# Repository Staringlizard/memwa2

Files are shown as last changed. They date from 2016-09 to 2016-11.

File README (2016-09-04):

*** Building software:

1. Download the gnu arm cross compiler package
2. Download memwa2 source code from github
3. Extract everything and enter folder memwa2
4. Modify PATH variable to include the bin folder for cross compiler
5. Make
6. Done

*** Flashing software:

1. Copy the file ./out_target/target.bin to the root directory on the sdcard
2. Insert the SD card and startup hardware
3. New firmware will automatically start flash procedure if firmware file is found
4. If software is flashed successfully the target.bin file will be removed

*** SD card:

There are some folders that can be added to the sdcard
in order to configure the software and to run programs.

"conf" folder

  "key.cfg" file

    This file contain entries like this -> "2A:0,0". This specific entry
    means that the USB scan code 2A (back space) should be mapped
    to the commodore key matrix equivalent of 0 and 0. In other words
    the CIA1 IC portA bit 0 and CIA1 portB bit 0 will have a connection.

  "palette.cfg" file

    This file contains all c64 colors in RGB888 format. In addition to this
    it also contains 3 extra colors that are used for text background,
    text forground and marker.

"d64, t64, tap, prg" folders

    Here all programs should be stored.

"rom" folder

    "cc_brom.bin"

      Contains the basic rom.

    "cc_crom.bin"

      Contains the char rom.

    "cc_krom.bin"

      Contains the kernal rom.

    "dd_dos.bin"

      Contains the disk drive rom.

"res" folder

  Contains the bitmaps used in menu.

*** Startup:

1. Unzip the sdcard.zip file onto an sdcard
2. Insert sdcard into memwa2 board
3. Power on

*** Key shortcuts:

Ctrl + Esc: Menu
Ctrl + F1: Show info
Ctrl + F2: Activate/deactivate disk drive
Ctrl + F3: Activate/deactivate freq lock
Ctrl + F4: Full/half emulated frame rate
Ctrl + F5: Play/Stop datasette
Ctrl + F6: Clear last message
Ctrl + F9: C64 palette
Ctrl + F10: C64 soft reset
Ctrl + F11: C64 hard reset
Ctrl + F12: Hardware reset
Joystick A: Arrow keys
Joystick B: Num keys

*** Design:

             +-----+ +-----+ +-----+ +-----+ +-----+ +-----+    +-----+ +-----+ +-----+ +-----+     ^
Emulators    | vic | | tap | | sid | | cia | | cpu | | bus |    | via | | fdd | | cpu | | bus |     |
             +-----+ +-----+ +-----+ +-----+ +-----+ +-----+    +-----+ +-----+ +-----+ +-----+     |
                                                                                                    |
             +---------------------------------------------+    +-----------------------------+     +
             |                   emuccif                   |    |            emuddif          |  Emulator
             +----------------------+----------------------+    +---------------+-------------+
Interface                           |                                           |
             +----------------------+-------------------------------------------+-------------+
             |                                    hostif                                      |  Hardware
             +--------------------------------------------------------------------------------+     +
                                                                                                    |
                                               +-----------+                                        |
Higher layer                           +-------+    sm     |                                        |
                                       |       +-----+-----+                                        |
                                       |             |                                              |
                                 +-----+----+  +-----+-----+  +-----------+                         |
Util layer                       |   stage  |  |   keybd   |  |  console  |                         |
                                 +----------+  +-----+-----+  +---------+-+                         |
                                                     |                  |                           |
                                 +-----------+       | +------------+   |                           |
Mware layer                      |   fatfs   |       +-+    usb     +---+                           |
                                 +-----------+         +------------+                               |
                                                                                                    |
             +-------+ +---+ +----+ +-----+ +---+ +------+ +-----+ +------+ +-------+ +-------+     |
Driver layer |adv7511| |crc| |disp| |joyst| |rng| |sdcard| |sdram| |sidbus| |usbd_ll| |usbh_ll|     |
             +-------+ +---+ +----+ +-----+ +---+ +------+ +-----+ +------+ +-------+ +-------+     |
                                                                                                    |
             +--------------------------------------------------------------------------------+     |
HAL layer    |                                      HAL                                       |     |
             +--------------------------------------------------------------------------------+     v

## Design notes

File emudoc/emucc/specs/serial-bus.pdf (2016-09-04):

IEC-bus documentation as used for the 1541-III

J. Derogee | Page 1 | 2008-02-24

# IEC disected

This document describes the IEC-bus information gathered during the development of the 1541-III.

J. Derogee | Page 2 | 2008-02-24

General info:

The serial (IEC) bus uses a synchronous protocol. There are three lines: DATA, CLK, and -ATN. The lines are driven by a 6526 CIA on the C-64, through open-collector inverters (7406's); 1 kohm pull-up resistors are used. The 1541 and 1571 drives do the same, but they don't drive the -ATN line, and they use 6522 VIA's. The lines are also read, directly by the C-64. Address $DD00 (PA of CIA2) is used by the C-64. Bit 3 is ATN OUT, bit 4 is -CLK OUT, bit 5 is -DATA OUT, bit 6 is CLK IN, and bit 7 is DATA IN.

A device's identity is usually stored in RAM after boot up, so a drive POKE will let it change to anything in the range 0-30. The C64 kernal (unless patched) prevents 0-3 from actually going down the serial bus....

CBM Device ID’s
Device ID | Device type
0 | Keyboard
1 | Cassette port
2 | RS232 on user port or second cassette on older units
3 | Screen
4 | Printer
5 | Printer
6 | Typically plotter device
7 | Second plotter? Also used by a freeze cartridges named TurboTape, but that's only an internal definition
8 | Primary Disk Drive
9 | Disk Drive
10 | Disk Drive Also used by some serial-to-parallel printer interface cartridges
11 | Disk Drive
12 | Disk Drive
13 | Disk Drive
14 | Disk Drive Sometimes used by some serial-to-parallel printer interface cartridges
15 | Disk Drive
16-30 | Unknown
31 | Device #31 is reserved as a command to all devices Devices will not ignore a command to #31, since they cannot do this. Sending a TALK command to #31 means UNTALK, sending a LISTEN to #31 means UNLISTEN. This however is just a statement found on the web and has not been verified by other sources.

J. Derogee | Page 3 | 2008-02-24

Regarding the signals on the bus: 0V = TRUE or PULLED DOWN
5V = FALSE or RELEASED

Regarding the data on the bus: 0V = logical 0
5V = logical 1

Bytes are sent with low bit first. Data is valid on rising edge of clock

CBM Serial Bus Control Codes
Base address | Command name and details
20 | LISTEN + device number (0-30)
3F | UNLISTEN
40 | TALK + device number (0-30)
5F | UNTALK
60 | OPEN CHANNEL / DATA + Secondary Address / channel (0-15)
70 | -Undefined-
80 | -Undefined-
90 | -Undefined-
A0 | -Undefined-
B0 | -Undefined-
C0 | -Undefined-
D0 | -Undefined-
E0 | CLOSE + Secondary Address / channel (0-15)
F0 | OPEN + Secondary Address / channel (0-15)
/ | = | byte is send under attention (ATN low)
↑ | = | bus turn around (computer is set to slave)
↓ | = | bus turn around (computer is set to master (normal situation)

Note: the device (1541) is called by the computer (C64)

J. Derogee | Page 4 | 2008-02-24

This article appeared in Compute! July 1983 and is Copyrighted 1983 by Jim Butterfield.

HOW THE VIC/64 SERIAL BUS WORKS By Jim Butterfield

The Serial bus connects VIC or Commodore 64 to its major peripherals, especially disk and tape. The workings of this interface have been a source of bafflement to most of us. We know that it's somehow related to the IEEE-488 bus which is used on PET and CBM computers. But it has fewer wires, and it's slower. For anyone interested in interfacing details, this article will clear up the mystery.

GROUND RULES
To understand the workings of this bus, you must work through a few concepts. Later, we'll get technical for this who want it. The bus, like the IEEE, has two modes of operation: Select mode, in which the computer calls all devices and asks for a specific device to remain connected after the call ("Jones, would you stay in my office after the meeting?"); and Data mode, in which actual information is transmitted ("Jones, I've decided to give you a raise"). Select mode is invoked by the use of a special control line called "Attention," or ATN. By using Select mode, you can call in any device you choose, but you may need to do more before you transmit data. You might have several disk files in progress - writing some and reading others – and when you select the disk, device 8, you'll still need to specify which "part" of the disk you want to reach: subchannel 3, subchannel 15, or whatever. To do this, we use a "secondary address" which usually signals a subsystem within a specific device. That goes in as part of the command during Select mode. Finally, we may need to send other control information: the name of the file we wish to open, for example. That's not data; it's device setup information, so we also send it in Select mode. But the main part is: you select a device, and then you send to it or receive from it. Finally, you shut it off. All devices are connected, but only the one you have selected will listen or talk.

If you're not into volts and signals and things, the rest of this article may not do much for you. I want to talk about technical aspects of the bus. First, all the data flows over two wires; They are called the Clock line and the Data line. There are other wires used for control purposes, but the data uses only the two main ones. All wires connect to all devices. The wires don't go "one way"; any device can put a ground on a signal line, and all other devices will see it. Indeed, that's the secret of how it works: each wire serves as a common signal bus.

When no device puts a ground on a signal line, the voltage rises to almost five volts. We call this the "false" logic condition of the wire. If any device rounds the line, the voltage drops to zero; we call this the "true" condition of the line. Note that if two devices signal "true" on a line (by grounding it), the effect is exactly the same as if only one has done so: the voltage is zero and that's that. We can summarize this as an important set of logic rules:

-A line will become "true" (PULLED DOWN, or 0V) if one or more devices signal true;
-A line will become "false" (RELEASED, or 5V) only if all devices signal false.

Remember that we have several lines, but the important ones for information transmission are the Clock line and the Data line. Let's watch them work.

J. Derogee | Page 5 | 2008-02-24

TRANSMISSION: STEP ZERO
Let's look at the sequence when a character is about to be transmitted. At this time, both the Clock line and the Data line are being held down to the true tate. With a test instrument, you can't tell who's doing it, but I'll tell you: the talker is holding the Clock line true, and the listener is holding the Data line true. There could be more than one listener, in which case all of the listeners are holding the Data line true. Each of the signals might be viewed as saying, "I'm here!".
STEP 1: READY TO SEND
Sooner or later, the talker will want to talk, and send a character. When it's ready to go, it releases the Clock line to false. This signal change might be translated as "I'm ready to send a character." The listener must detect this and respond, but it doesn't have to do so immediately. The listener will respond to the talker's "ready to send" signal whenever it likes; it can wait a long time. If it's a printer chugging out a line of print, or a disk drive with a formatting job in progress, it might hold back for quite a while; there's no time limit.
STEP 2: READY FOR DATA
When the listener is ready to listen, it releases the Data line to false. Suppose there is more than one listener. The Data line will go false only when all listeners have released it - in other words, when all listeners are ready to accept data. What happens next is variable. Either the talker will pull the Clock line back to true in less than 200 microseconds - usually within 60 microseconds - or it will do nothing. The listener should be watching, and if 200 microseconds pass without the Clock line going to true, it has a special task to perform: note EOI.

INTERMISSION: EOI
If the Ready for Data signal isn't acknowledged by the talker within 200 microseconds, the listener knows that the talker is trying to signal EOI. EOI, which formally stands for "End of Indicator," means "this character will be the last one." If it's a sequential disk file, don't ask for more: there will be no more. If it's a relative record, that's the end of the record. The character itself will still be coming, but the listener should note: here comes the last character. So if the listener sees the 200 microsecond time-out, it must signal "OK, I noticed the EOI" back to the talker, I does this by pulling the Data line true for at least 60 microseconds, and then releasing it. The talker will then revert to transmitting the character in the usual way; within 60 microseconds it will pull the Clock line true, and transmission will continue. At this point, the Clock line is true whether or not we have gone through the EOI sequence; we're back to a common transmission sequence.
STEP 3: SENDING THE BITS
The talker has eight bits to send. They will go out without handshake; in other words, the listener had better be there to catch them, since the talker won't wait to hear from the listener. At this point, the talker controls both lines, Clock and Data. At the beginning of the sequence, it is holding the Clock true, while the Data line is released to false. the Data line will change soon, since we'll send the data over it. The eights bits will go out from the character one at a time, with

the least significant bit going first. For example, if the character is the ASCII question mark, which is written in binary as 00011111, the ones will go out first, followed by the zeros. Now, for each bit, we set the Data line true or false according to whether the bit is one or zero. As soon as that's set, the Clock line is released to false, signalling "data ready." The talker will typically have a bit in place and be signalling ready in 70 microseconds or less. Once the talker has signalled "data ready," it will hold the two lines steady for at least 20 microseconds timing needs to be increased to

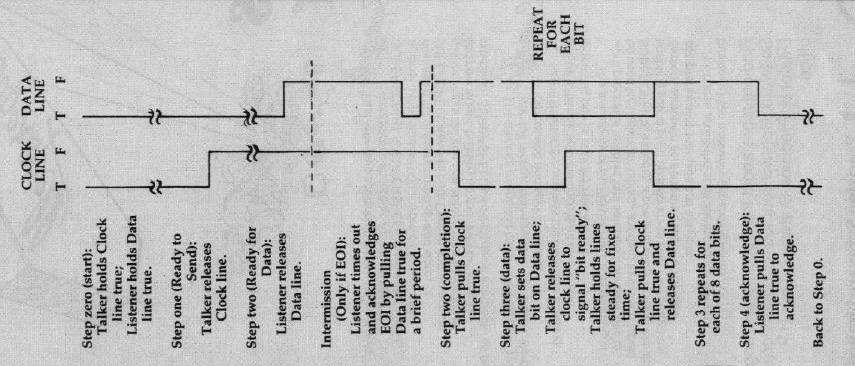
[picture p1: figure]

J. Derogee | Page 6 | 2008-02-24

60 microseconds if the Commodore 64 is listening, since the 64's video chip may interrupt the processor for 42 microseconds at a time, and without the extra wait the 64 might completely miss a bit. The listener plays a passive role here; it sends nothing, and just watches. As soon as it sees the Clock line false, it grabs the bit from the Data line and puts it away. It then waits for the clock line to go true, in order to prepare for the next bit. When the talker figures the data has been held for a sufficient length of time, it pulls the Clock line true and releases the Data line to false. Then it starts to prepare the next bit.

STEP 4: FRAME HANDSHAKE
After the eighth bit has been sent, it's the listener's turn to acknowledge. At this moment, the Clock line is true and the Data line is false. The listener must acknowledge receiving the byte OK by pulling the Data line to true. The talker is now watching the Data line. If the listener doesn't pull the Data line true within one millisecond - one thousand microseconds - it will know that something's wrong and may alarm appropriately.
STEP 5: START OVER
We're finished, and back where we started. The talker is holding the Clock line true, and the listener is holding the Data line true. We're ready for step 1; we may send another character - unless EOI has happened. If EOI was sent or received in this last transmission, both talker and listener "let go." After a suitable pause, the Clock and Data lines are released to false and transmission stops.

ATTENTION!
This is all very well for a transmission that's under way, but how do we set up talker and listener? We use an extra line that overrides everything else, called the ATN, or Attention line. Normally, the computer is the only device that will pull ATN true. When it does so, all other devices drop what they are doing and become listeners. Signals sent by the computer during an ATN period look like ordinary characters - eight bits with the usual handshake - but they are not data. They are "Talk," "Listen," "Untalk," and "Unlisten" commands telling a specific device that it will become (or cease to be) a talker or listener. The commands go to all devices, and all devices acknowledge them, but only the ones with the suitable device numbers will switch into talk and listen mode. These commands are sometimes followed by a secondary address, and after ATN is released, perhaps by a file name. An example might help give an idea of the nature of the communications

J. Derogee | Page 7 | 2008-02-24

that take place. To open for writing a sequential disk file called "XX," the following sequence would be sent with ATN on:DEVICE-8-LISTEN;SECONDARY-ADDRESS-2-OPEN. When ATN switches off, the computer will be waiting as a talker, holding the Clock line true; and the disk will be the listener, holding the Data line true. That's good, because the computer has more to send, and it will transmit: X;X;comma;s;comma;W - the W will be accompanied with an EOI signal. Shortly thereafter, the computer will switch ATN back on and send DEVICE-8-UNLISTEN. The file is now open; later, the computer will want to send data there. It will transmit, with ATN on, DEVICE-8-LISTEN;SECONDARY- ADDRESS-2-DATA. Then the computer releases the ATN line and sends
its data; only the disk will receive the data, and the disk will know to put it onto the file called XX. The last character sent by the computer will also signal EOI. After the computer has sent enough data for the moment, it will pull ATN on again and send DEVICE-8-UNLISTEN. Many bursts of data may goto the file; eventually, the computer will close the file by sending (with ATN on, of course) DEVICE-8-LISTEN;SECONDARY-ADDRESS-2-CLOSE. ATN overrides everything in progress, A disk file might have lots of characters to give to the computer, but the computer wants only a
little data. It accepts the characters it wants, then switches on ATN and commands the disk to Untalk. The disk has not sent EOI, but it will disconnect as commanded. Later, when it's asked to Talk again, it will send more characters.

ATN SEQUENCES
When ATN is pulled true, everybody stops what they are doing. The processor will quickly pull the Clock line true (it's going to send soon), so it may be hard to notice that all other devices release the Clock line. At the same time, the processor releases the Data line to false, but all other devices are getting ready to listen and will each pull Data to true. They had better do this within one millisecond (1000 microseconds), since the processor is watching and may sound an alarm ("device not available") if it doesn't see this take place. Under normal circumstances, transmission now takes place as previously described. The computer is sending commands rather than data, but the characters are exchanged with exactly the same timing and handshakes as before. All devices receive the commands, but only the specified device acts upon it. This results in a curious situation: you can send a command to a nonexistent device (try "OPEN 6,6") - and the computer will not know that there is a problem, since it receives valid handshakes from the other devices. The computer will notice a problem when you try to send or receive data from the nonexistent device, since the unselected devices will have dropped off when ATN ceased, leaving you with nobody to talk to.

TURNAROUND
An unusual sequence takes place following ATN if the computer wishes the remote device to become a talker. This will usually take place only after a Talk command has been sent. Immediately after ATN is released, the selected device will be behaving like a listener. After all, it's been listening during the ATN cycle, and the computer
has been a talker. At this instant, we have "wrong way" logic; the device is holding down the Data line, and the computer is holding the Clock line. We must turn this around. Here's the sequence: the computer quickly realizes what's going on, and pulls the Data line to true (it's already there), as well as releasing the Clock line to false. The device waits for this: when it sees the Clock line go true, it releases the Data line (which stays true anyway since the computer is now holding it down) and then pulls down the Clock line. We're now in our starting position, with the talker (that's the device) holding the Clock true, and the listener (the computer) holding the Data line true. The

J. Derogee | Page 8 | 2008-02-24

computer watches for this state; only when it has gone through the cycle correctly will it be ready to receive data. And data will be signalled, of course, with the usual sequence: the talker releases the Clock line to signal that it's ready to send. The logic sequences make sense. They are hard to watch with a voltmeter or oscilloscope since you can't tell which device is pulling the line down to true. The principles involved are very similar to those on the PET/CBM IEEE-488 bus - the same Talk and Listen commands go out, with secondary addresses and similar features. There are fewer "handshake" lines than on IEEE, and the speed is slower; but the principle is the same.

-End of document-Copyright 1983 by Jim Butterfield (published in Compute!)

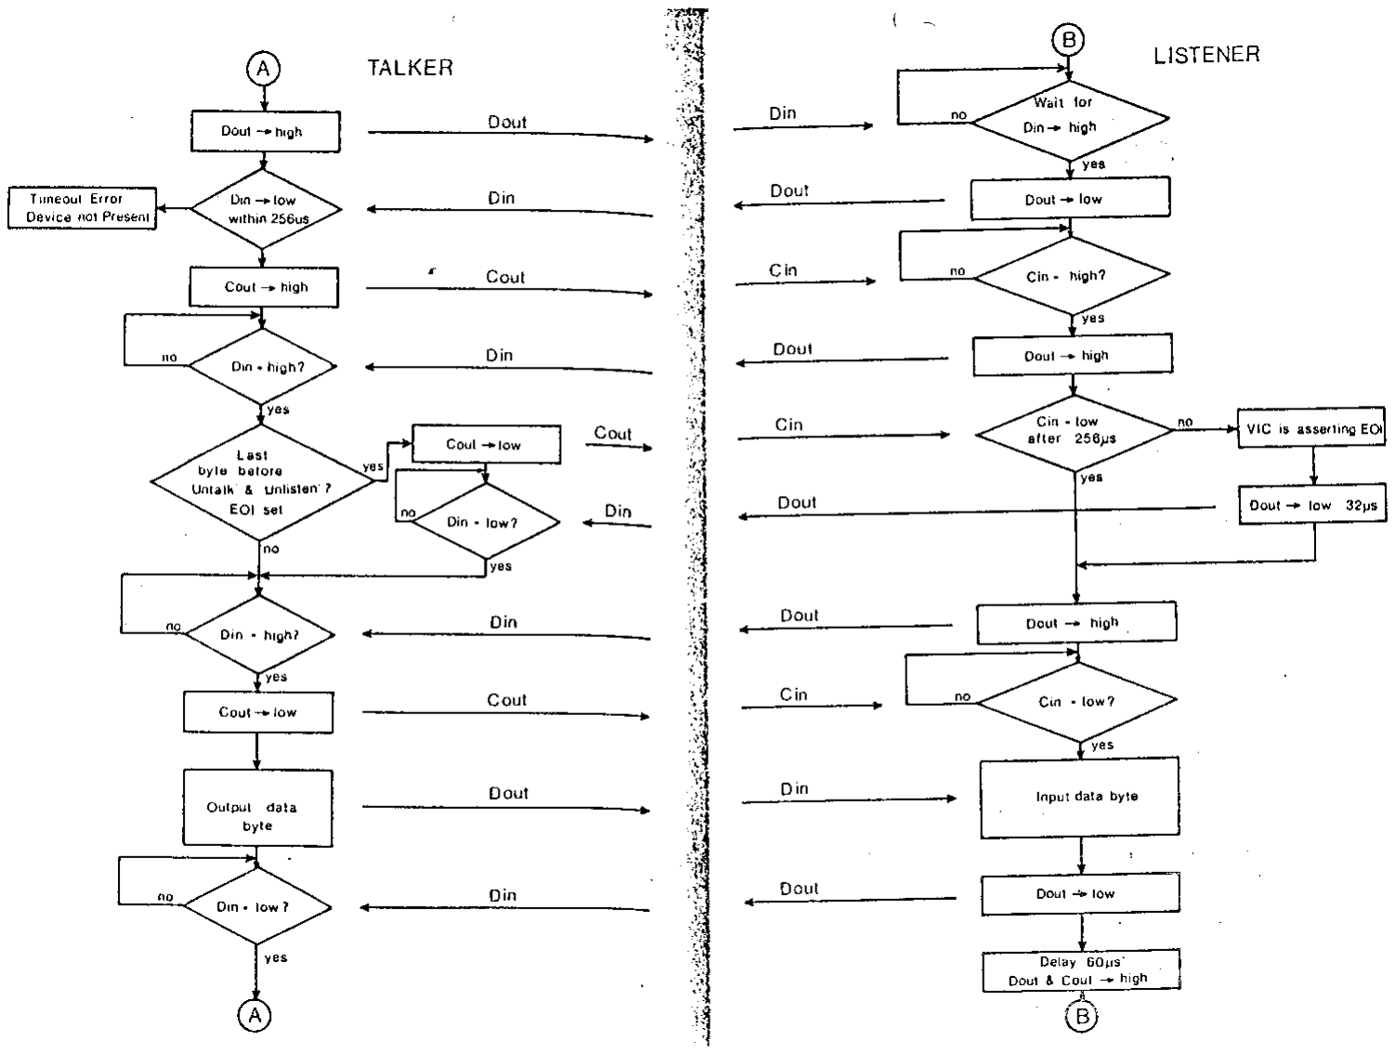
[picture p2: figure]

J. Derogee | Page 9 | 2008-02-24

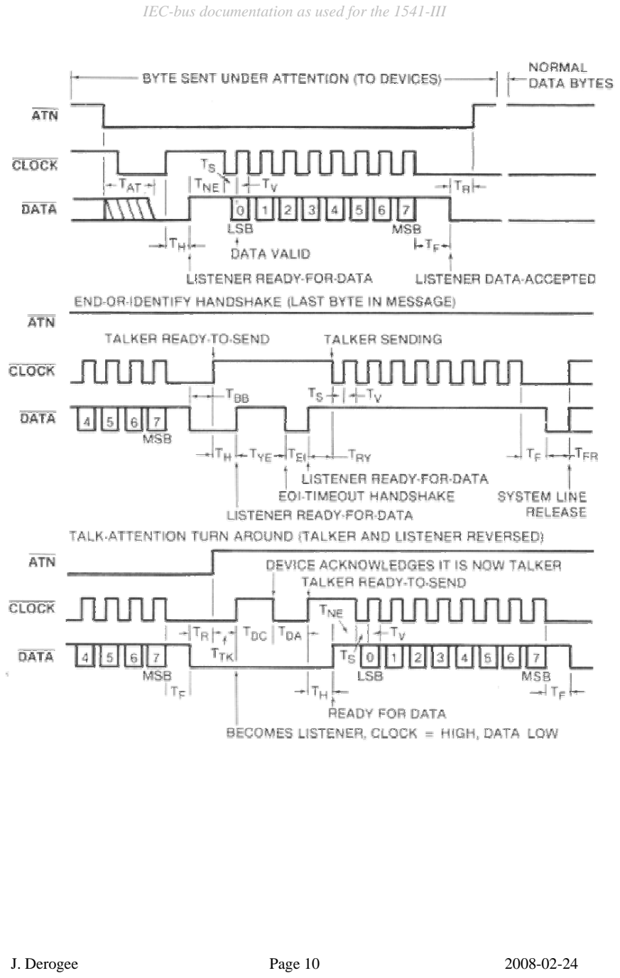
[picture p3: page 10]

J. Derogee | Page 10 | 2008-02-24

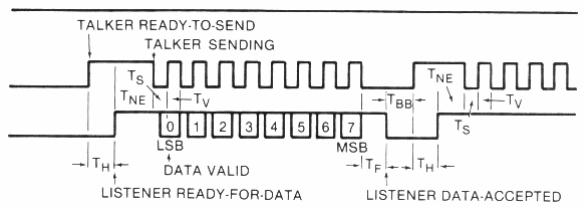
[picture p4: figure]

J. Derogee | Page 11 | 2008-02-24

CBM Serial Bus Control Codes
Description | Symbol | Min. | Typ. | Max.
ATN RESPONSE (REQUIRED)¹ | TAT | - | - | 1000µs
LISTENER HOLD-OFF | TH | 0 | - | infinite
NON-EOI RESPONSE TO RFD² | TNE | - | 40µs | 200µs
BIT SET-UP TALKER⁴ | TS | 20µs | 70µs | -
DATA VALID | TV | 20µs | 20µs | -
FRAME HANDSHAKE³ | TF | 0 | 20 | 1000µs
FRAME TO RELEASE OF ATN | TR | 20µs | - | -
BETWEEN BYTES TIME | TBB | 100µs | - | -
EOI RESPONSE TIME | TYE | 200µs | 250µs | -
EOI RESPONSE HOLD TIME⁵ | TEI | 60µs | - | -
TALKER RESPONSE LIMIT | TRY | 0 | 30µs | 60µs
BYTE-ACKNOWLEDGE⁴ | TPR | 20µs | 30µs | -
TALK-ATTENTION RELEASE | TTK | 20µs | 30µs | 100µs
TALK-ATTENTION ACKNOWLEDGE | TDC | 0 | - | -
TALK-ATTENTION ACK. HOLD | TDA | 80µs | - | -
EOI ACKNOWLEDGE | TFR | 60µs | - | -

Notes:
1: If maximum time exceeded, device not present error.
2: If maximum time exceeded, EOI response required.
3: If maximum time exceeded, frame error.
4: TV and TPR minimum must be 60µs for external device to be a talker. 5: TEI minimum must be 80µs for external device to be a listener.

J. Derogee | Page 12 | 2008-02-24

Serial Bus Pinouts
Pin | Pin name and function
1 | SRQ : Serial Service Request In
2 | GND : Ground
3 | ATN : Serial Attention In/Out
4 | CLK : Serial Clock In/Out
5 | DATA : Serial Data In/Out
6 | RESET : Serial Reset

SRQ: Serial Service Request In:
This signal is not used on the C64. On C128 it is replaced with Fast Serial Clock for the 1571 disk drive.

ATN: Serial Attention In/Out:
Sending any byte with the ATN line low (sending under attention) causes it to be interpreted as a Bus Command for peripherals on the serial bus. When the C64 brings this signal LOW, all other devices start listening for it to transmit an address. The device addressed must respond in a preset period of time; otherwise, the C64 will assume that the device addressed is not on the bus, and will return an error in the STATUS word.

CLK: Serial Clock In/Out:
This signal is for timing the data sent on the serial bus. This signal is always generated by the active TALKER. RISING EDGE OF THE CLOCK means data bit is valid.

DATA: Serial Data In/Out:
Data on the serial bus is transmitted bit by bit at a time on this line.

RESET: Serial Reset:
Some say that you may disconnect this line to save your disk drive, but in fact resetting the drive when you reset your computer is very logical and is the only way to reset your drive whithout switching it OFF and ON.

IEC connector
(on rear of CBM computer)

DIN, 6 pole, female

J. Derogee | Page 13 | 2008-02-24

NORMAL OPERATION:

Read file from device#8

LOAD”filename”,8,1

/28 /F0 filename /3F
/48 /60 ↑read data↓ /5F
/28 /E0 /3F

Write file to device#8

SAVE”filename”,8,1

/28 /F0 filename /3F
/28 /60 send data /3F
/28 /E0 /3F

FILE NOT FOUND SITUATION:

Read file from device#8

LOAD”filename”,8,1

/28 /F0 filename /3F
/48 /60 ↑↓ release data and clock This situation is recognized by the computer as an error /28 /E0 /3F

READING THE ERRORCHANNEL:

OPEN 15,8,15 This line does not start IEC traffic, it prepares the computer for communication INPUT#15,A,B$,C,D
PRINT A,B$,C,D
CLOSE 15
/48 | /6F | ↑ | 30 | 30 | 2C | 20 | …
TALK #8 | DATA ch15 Turn ‘0’ | ‘0’ | ‘,’ | ‘SPACE’ | …

Reading the error channel only works when no file has been opened on channel 15.

J. Derogee | Page 14 | 2008-02-24

The difference between a 2-line and a single line command to the 1541 drive :

Scratch a file name “T” on a media inside device#8

OPEN 15,8,15 ◄this line does not start IEC traffic, it prepares the computer for communication PRINT#15,”S:T”

/28 | /6F | 53 | 3A | 54 | 0D | /3F
LISTEN #8 | DATA ch15 | ‘S’ | ‘:’ | ‘T’ | ‘CR’ | UNLISTEN

OPEN 15,8,15,”S:T”

/28 | /FF | 53 | 3A | 54 | /3F
LISTEN #8 | OPEN ch15 | ‘S’ | ‘:’ | ‘T’ | UNLISTEN

J. Derogee | Page 15 | 2008-02-24

To send a data byte to a drive, that device must first be "listened". If the Secondary address (from here referred to as: SA or channel) is 15, the drive will interpret the data as a DOS command. A DOS command is executed when the drive is UNLISTENed ($3F).

If the channel is not 15, DOS will ignore it unless you first sent an OPEN.
An OPEN is sent to tell DOS where you want your data to go.
That is done by LISTENing the device. With -ATN high, a character string must be sent. That will be either a filename (to open a write file), or something like "#", "#2", etc. That tells DOS to write your data to one of the five DOS buffers. Then, with -ATN low, send an UNLISTEN.
channel = 0 is reserved for a reading a PRG file.
channel = 1 is reserved for a writing a PRG file.
channel = 2-14 need the filetype and the read/write flag in the filename as ",P,W" for example. channel = 15 for DOS commands or device status info.

After the OPEN is sent, you can send a LISTEN using the channel used in the OPEN.
DOS has a table of opened files, and will use the channel to write your data to the corresponding file.

The purpose of a CLOSE, for a file named "#", is to free up that DOS buffer. For a file whose name appears in the disk directory, a CLOSE will set bit 7 of the filetype byte in the directory descriptor, update the block count, and save BAM back to disk. DOS will even turn off the drive-LED.

You can keep files open in several devices, and write data first to one and then another. Just UNLISTEN a device before LISTENing another. You can have a drive with a "LISTEN" device address of 8 and a "TALK" device address of 9. Another drive can use 8 for both "LISTEN" and "TALK" device addresses. That is how you can download a file to both devices at the same time, and still be able to read the individual error channels.

The KERNAL routines, when the computer is sending data, always buffer one byte. The KERNAL UNLISTEN, UNTALK, LISTEN, and TALK routines check for a buffered byte. If one is present, it is sent delayed. Then the routine does its regular job.

J. Derogee | Page 16 | 2008-02-24

To open a file in a disk drive, there is no need also to open a file in the computer. However, that is usually done for the sake of convenience. But the KERNAL LOAD and SAVE routines open read and write files in the IEC (serial) device, without also opening files in the computer. To open a file in an IEC device, the -ATN line must be taken low (by setting bit 3 of $DD00). Then, the CLK line is taken low (bit 4 of $DD00 is set), and the computer waits for one millisecond. After which the device number ORed with $20 is sent via slow serial. With -ATN still low, the channel ORed with $F0 is then sent; -ATN is then taken high. Next, the filename string is sent to the drive, still using slow serial. The string is terminated by "=", by ",", or by a count of 16 characters, whichever comes first. If the drive DOS encounters ",a" or ",a,b" (where "a" and "b" may be any characters), it uses that information to determine file type and data direction. If the character is not valid it is tossed; there is no error. First direction is checked; "w" is "write" and "r" is "read". That may be overridden by the channel; an channel of 0 defines "read" and an channel of 1 defines "write". For any other channel (2 to 14), if there is no direction character, "read" is set. DOS then looks for a file type characater; "u" is "usr", "p" is "prg", and "s" is "seq". If the direction is "read", and there is no file type character, ANY file type is acceptable. An exception occurs for no file type character and an channel of 0; that defines "prg". If the direction is "write", and there is no file type character, "seq" is set. An exception occurs for no file type character and an channel of 1; that defines "prg". In the special case of the string's being ",w", the infamous "comma" filename will appear in the directory of a 1541 disk. This C-64 BASIC program will write 144 files named "," to a freshly formatted disk. The files cannot be directly deleted.

10 fori=1to144:open8,8,8,",w":close8
20 next

After the string is sent, the device is UNLISTENed. -ATN is taken low, CLK is taken low, the computer waits for one ms, and $3F is sent to the device. The file is now opened in the device; the file may be closed by doing a modified OPEN. No string is sent, and the channel is ORed with $E0 rather than with $F0. Between the OPEN and the CLOSE, data may be read from a "read" file by TALKing the drive, or written to a "write" file by LISTENing the drive. Also, a device may be UNTALKed or UNLISTENed. For LISTEN, the device number ORed with $20 is sent as with OPEN or CLOSE. Then, with -ATN still low, the channel is sent ORed with $60. -ATN is then taken high. For TALK, it's the same, except that the device number is ORed with $40. Also for TALK, after the channel is sent, the bus must be "turned around". That is accomplished by taking the DATA line low (setting bit 5 of $DD00), taking the -ATN line high (clearing bit 3 of $DD00), taking the CLK line high (clearing bit 4 of $DD00), and looping until the CLK line is low (until bit 6 of $DD00 is clear). For UNLISTEN and UNTALK, just one byte is sent (in the same manner as the device number is sent for LISTEN, TALK, etc.). That byte is $3F for UNLISTEN and $5F for UNTALK; ALL devices on the bus are commanded either to close their ears or to shut up. After the byte is sent, -ATN is taken high.

J. Derogee | Page 17 | 2008-02-24

How to change the device number without changing the jumpers

This actually works on all the drives. It works on all the variations of the 1541, plus the 1571, 1581, and all the CMD drives including the RAMLink and the RAMDrive.
If you want to disable a drive, modify line 20 so it will accept a value of 1. Since no software will ever attempt to access device 1 the drive will never respond and will sit there quietly even though it is still turned on. If you still want to be able to bring it back to life, change the device number to 6 or 7. Very few programs ever look for anything below device 8.

5 INPUT "OLD DEVICE NUMBER";ODV
10 INPUT "NEW DEVICE NUMBER";DV
20 IF DV<8 OR DV>11 THEN 10
30 OPEN 15,ODV,15
40 PRINT#15,"M-W"CHR$(119)CHR$(0)CHR$(2)CHR$(DV+32)CHR$(DV+64) 50 CLOSE 15

J. Derogee | Page 18 | 2008-02-24

A brief history of the IEC-bus By Jim Butterfield

As you know, the first Commodore computers used the IEEE bus to connect to peripherals such as disk and printer. I understand that these were available only from one source: Belden cables. A couple of years into Commodore's computer career, Belden went out of stock on such cables (military contract? who knows?). In any case, Commodore were in quite a fix: they made computers and disk drives, but couldn't hook 'em together! So Tramiel issued the order: "On our next computer, get off that bus. Make it a cable anyone can manufacture". And so, starting with the VIC-20 the serial bus was born. It was intended to be just as fast as the IEEE-488 it replaced.

"Technically, the idea was sound: the 6522 VIA chip has a "shift register" circuit that, if tickled with the right signals (data and clock) will cheerfully collect 8 bits of data without any help from the CPU. At that time, it would signal that it had a byte to be collected, and the processor would do so, using an automatic handshake built into the 6522 to trigger the next incoming byte. Things worked in a similar way outgoing from the computer, too. We early PET/CBM freaks knew, from playing music, that there was something wrong with the 6522's shift register: it interfered with other functions. The rule was: turn off the music before you start the tape! (The shift register was a popular sound generator). But the Commodore engineers, who only made the chip, didn't know this. Until they got into final checkout of the VIC-20.

By this time, the VIC-20 board was in manufacture. A new chip could be designed in a few months (yes, the silicon guys had application notes about the problem, long since), but it was TOO LATE!

A major software rewrite had to take place that changed the VIC-20 into a "bit-catcher" rather than a "character-catcher". It called for eight times as much work on the part of the CPU; and unlike the shift register plan, there was no timing/handshake slack time. The whole thing slowed down by a factor of approximately 5 to 6.

When the 64 came out, the problem VIA 6522 chip had been replaced by the CIA 6526. This did not have the shift registerproblem which had caused trouble on the VIC-20, and at that time it would have been possible to restore plan 1, a fast serial bus. Note that this would have called for a redesign of the 1540 disk drive, which also used a VIA. As best I can estimate - and an article in the IEEE Spectrum magazine supports this - the matter was discussed within Commodore, and it was decided that VIC-20 compatibility was more important than disk speed. Perhaps the prospect of a 1541 redesign was an important part of the decision, since current inventories needed to be taken into account. But to keep the Commodore 64 as a "bit-banger", a new problem arose.

The higher-resolution screen of the 64 (as compared to the VIC-20) could not be supported without stopping the CPU every once in a while. To be exact: Every 8 screen raster lines (each line of text), the CPU had to be put into a WAIT condition for 42 microseconds, so as to allow the next line of screen text and color nybbles to be swept into the chip.(More time would be needed if sprites were being used). But the bits were coming in on the serial bus faster than that: a bit would come in about every 20uSec! So the poor CPU, frozen for longer than that, would miss some serial bits completely! Commodore's solution was to slow down the serial bus even more. That's why the VIC-20 has a faster serial bus than the 64, even though the 64 was capable, technically, of running many times faster.

Fast disk finally came into its own with the Commodore 128.

J. Derogee | Page 19 | 2008-02-24

## Commodore 64 serial bus functions

Address | Function
$ED09 | Send TALK command to serial bus. Input: A = Device number. Output: – Used registers: A.
$ED0C | Send LISTEN command to serial bus. Input: A = Device number. Output: – Used registers: A.
$ED40 | Flush serial bus output cache, at memory address $0095, to serial bus. Input: – Output: – Used registers: A.
$EDB9 | Send LISTEN secondary address to serial bus. Input: A = Secondary address. Output: – Used registers: A.
$EDC7 | Send TALK secondary address to serial bus. Input: A = Secondary address. Output: – Used registers: A.
$EDDD | Write byte to serial bus. Input: A = Byte to write. Output: – Used registers: –
$EDEF | Send UNTALK command to serial bus. Input: – Output: – Used registers: A.
$EDFE | Send UNLISTEN command to serial bus. Input: – Output: – Used registers: A.
$EE13 | Read byte from serial bus. Input: – Output: A = Byte read. Used registers: A.

J. Derogee | Page 20 | 2008-02-24
$EE85 | Set CLOCK OUT to high. Input: – Output: – Used registers: A.
$EE8E | Set CLOCK OUT to low. Input: – Output: – Used registers: A.
$EE97 | Set DATA OUT to high. Input: – Output: – Used registers: A.
$EEA0 | Set DATA OUT to low. Input: – Output: – Used registers: A.
$EEA9 | Read CLOCK IN and DATA IN. Input: – Output: Carry = DATA IN; Negative = CLOCK IN; A = CLOCK IN (in bit #7). Used registers: A.
$F1AD | Read byte from serial bus; read $0D, Return, if device status != 0. Input: – Output: A = Byte read. Used registers: A.
$F237 | Define serial bus as standard input; do not send TALK secondary address if secondary address bit #7 = 1. Input: A = Device number. Output: – Used registers: A, X.
$F279 | Define serial bus as standard output; do not send LISTEN secondary address if secondary address bit #7 = 1. Input: A = Device number. Output: – Used registers: A, X.
$F3D5 | Open file on serial bus; do not send file name if secondary address bit #7 = 1 or file name length = 0. Input: – Output: – Used registers: A, Y.
$F528 | Send UNTALK and CLOSE command to serial bus. Input: – Output: – Used registers: A.

J. Derogee | Page 21 | 2008-02-24
$F63F | Send UNLISTEN and CLOSE command to serial bus. Input: – Output: – Used registers: A.
$F642 | Close file on serial bus; do not send CLOSE secondary address if secondary address bit #7 = 1. Input: – Output: – Used registers: –
$FE21 | Unknown. (Set serial bus timeout.) Input: A = Timeout value. Output: – Used registers: –

J. Derogee | Page 22 | 2008-02-24

Standard KERNAL functions
$FF93 | LSTNSA. Send LISTEN secondary address to serial bus. (Must call LISTEN beforehands.) Input: A = Secondary address. Output: – Used registers: A. Real address: $EDB9.
$FF96 | TALKSA. Send TALK secondary address to serial bus. (Must call TALK beforehands.) Input: A = Secondary address. Output: – Used registers: A. Real address: $EDC7.
$FFA2 | SETTMO. Unknown. (Set serial bus timeout.) Input: A = Timeout value. Output: – Used registers: – Real address: $FE21.
$FFA5 | IECIN. Read byte from serial bus. ( Must call TALK and TALKSA beforehands.) Input: – Output: A = Byte read. Used registers: A. Real address: $EE13.
$FFA8 | IECOUT. Write byte to serial bus. (Must call LISTEN and LSTNSA beforehands.) Input: A = Byte to write. Output: – Used registers: – Real address: $EDDD.
$FFAB | UNTALK. Send UNTALK command to serial bus. Input: – Output: – Used registers: A. Real address: $EDEF.
$FFAE | UNLSTN. Send UNLISTEN command to serial bus. Input: – Output: – Used registers: A. Real address: $EDFE.
$FFB1 | LISTEN. Send LISTEN command to serial bus. Input: A = Device number. Output: – Used registers: A. Real address: $ED0C.
$FFB1 | TALK. Send TALK command to serial bus. Input: A = Device number.

J. Derogee | Page 23 | 2008-02-24

Output: –
Used registers: A.
Real address: $ED09.

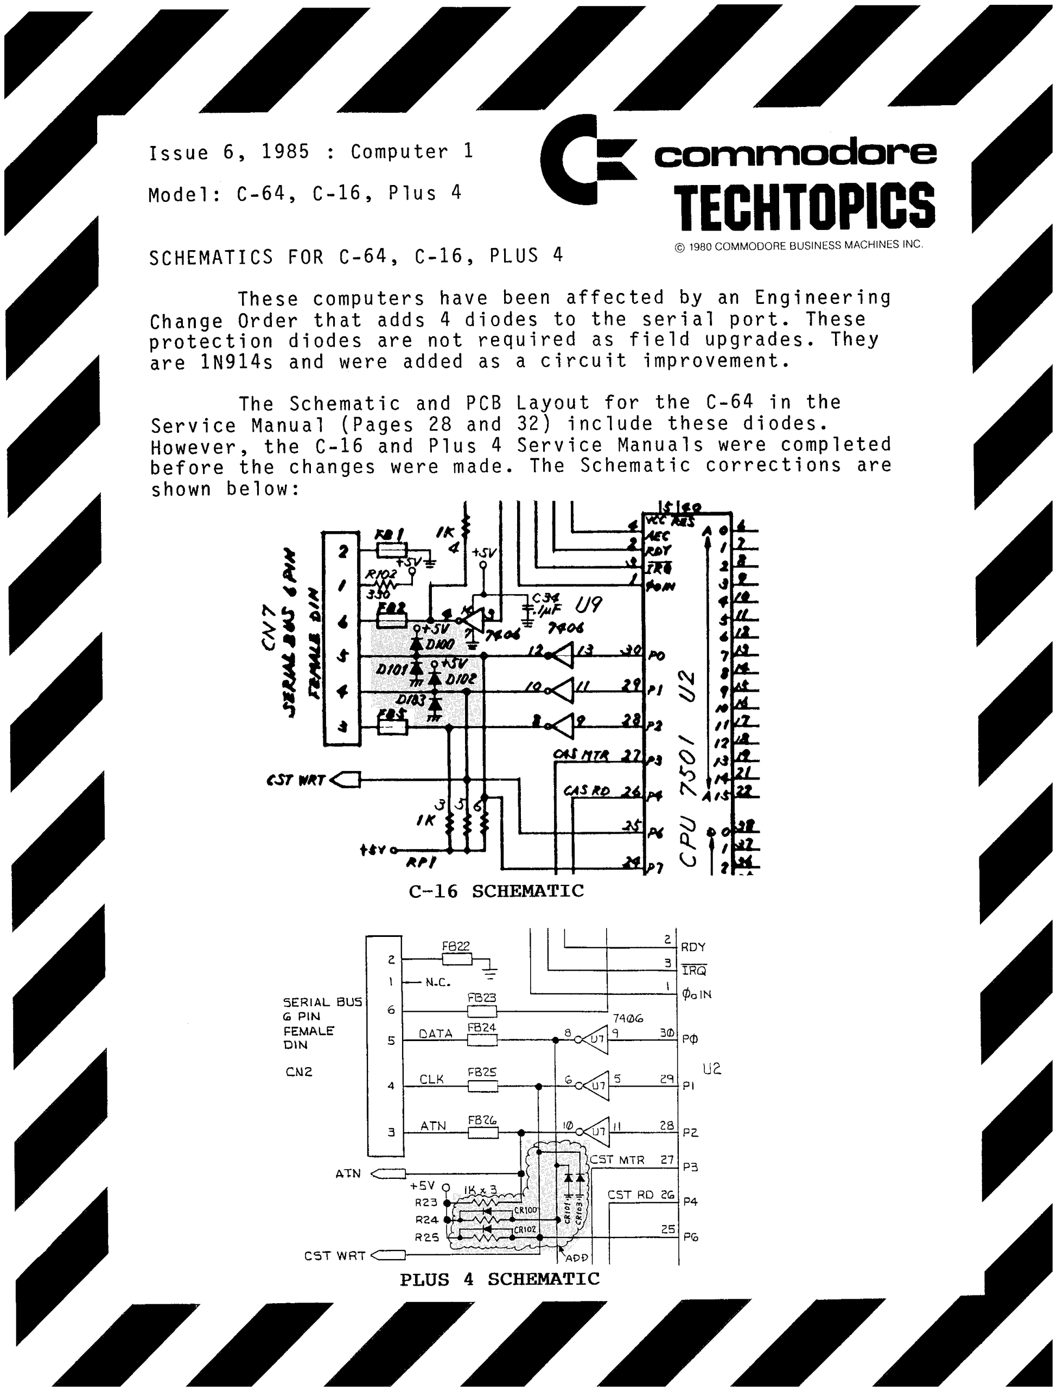
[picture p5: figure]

J. Derogee | Page 24 | 2008-02-24

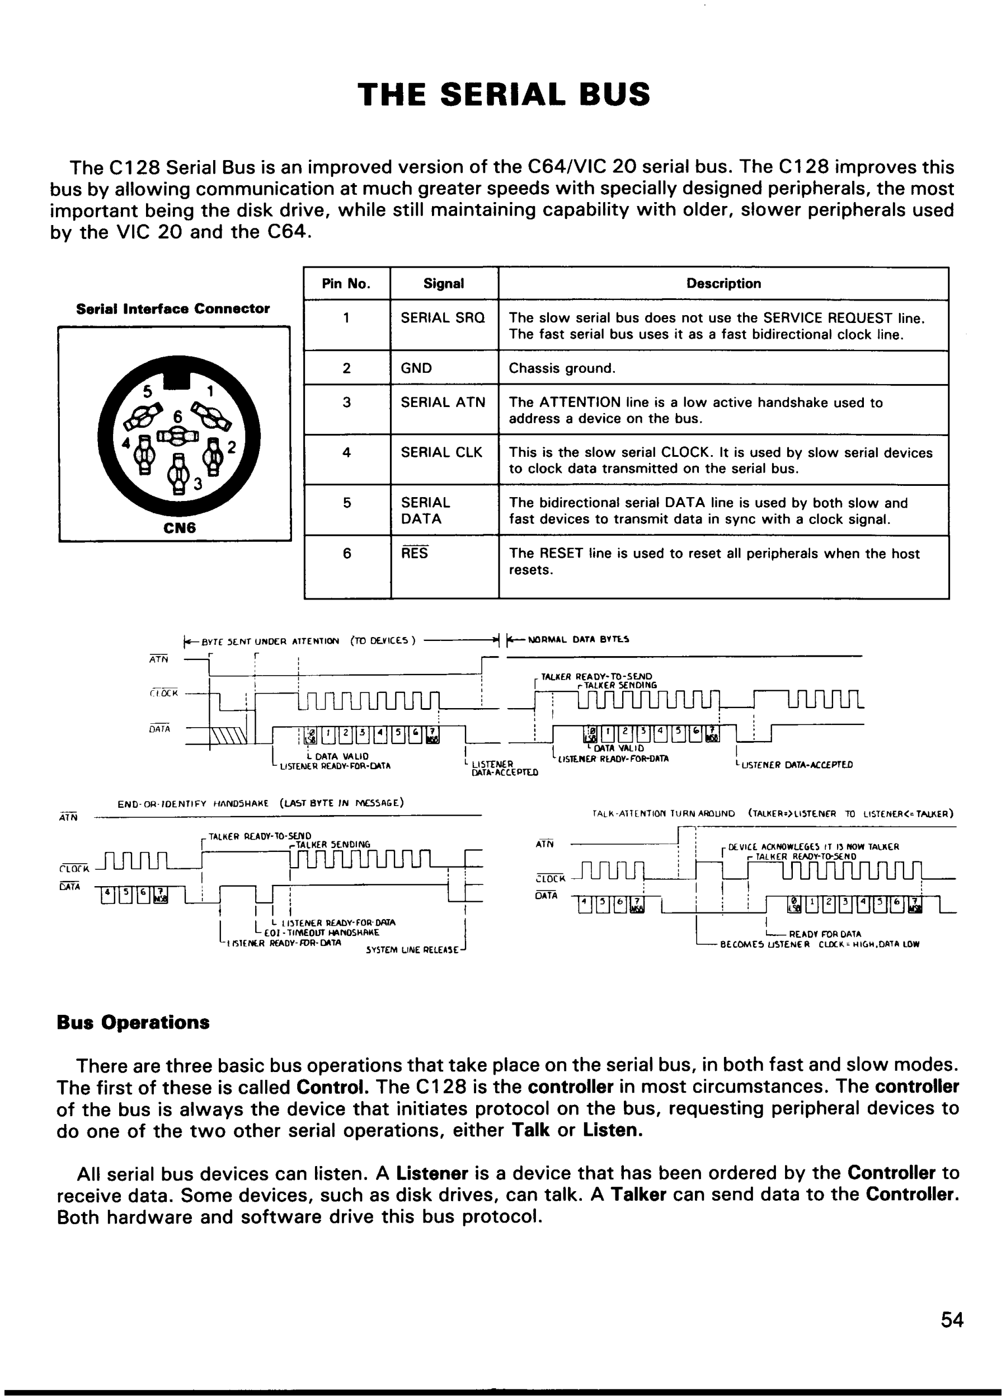
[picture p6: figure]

J. Derogee | Page 25 | 2008-02-24

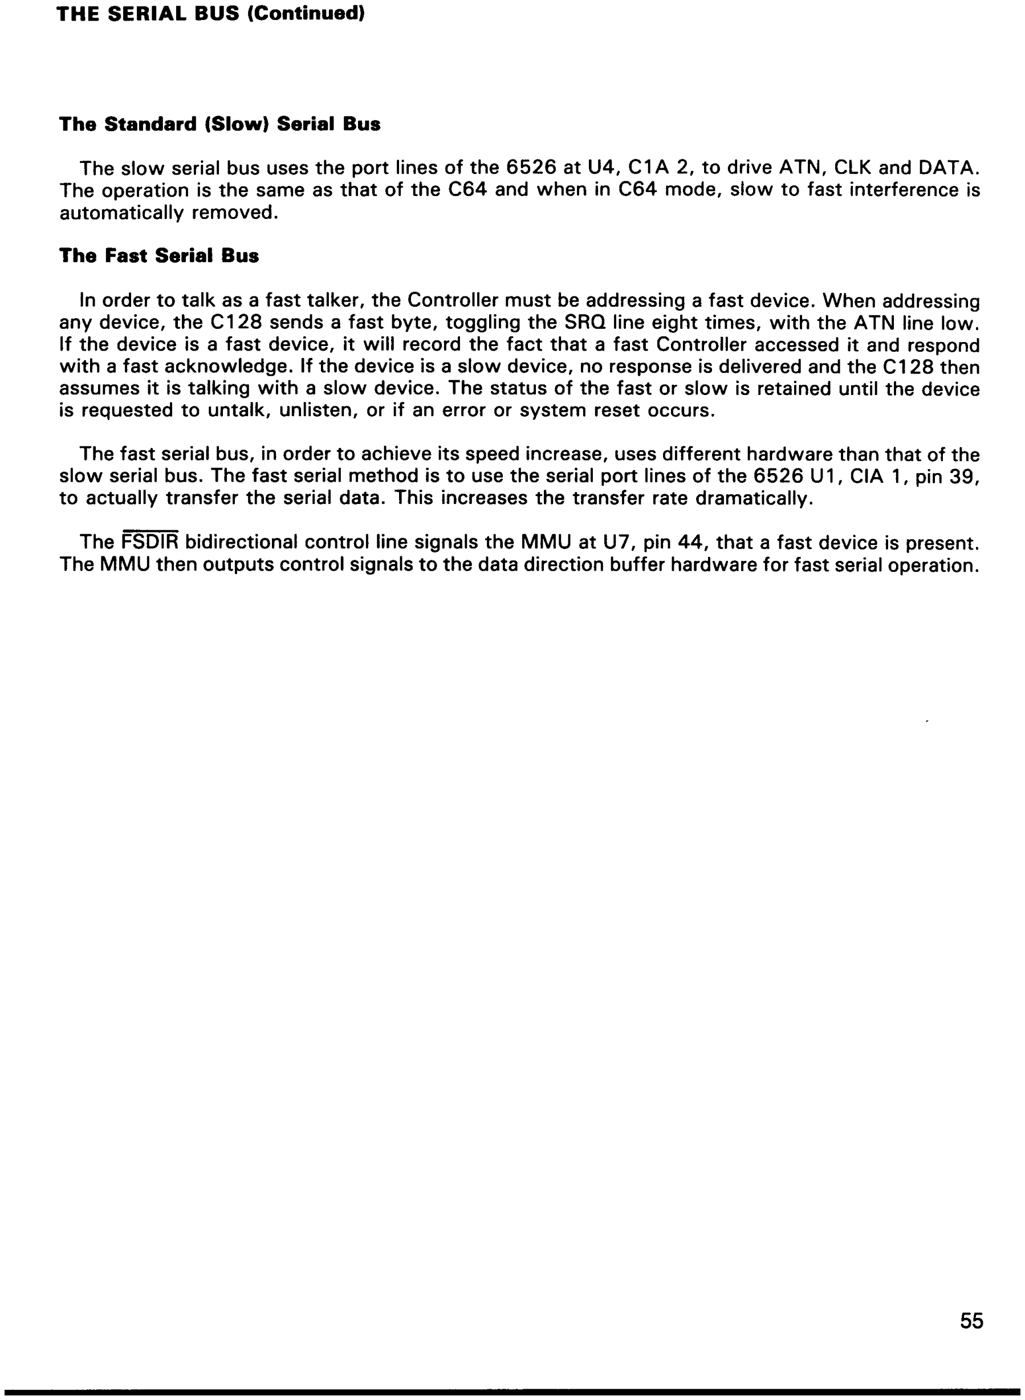
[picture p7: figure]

J. Derogee | Page 26 | 2008-02-24

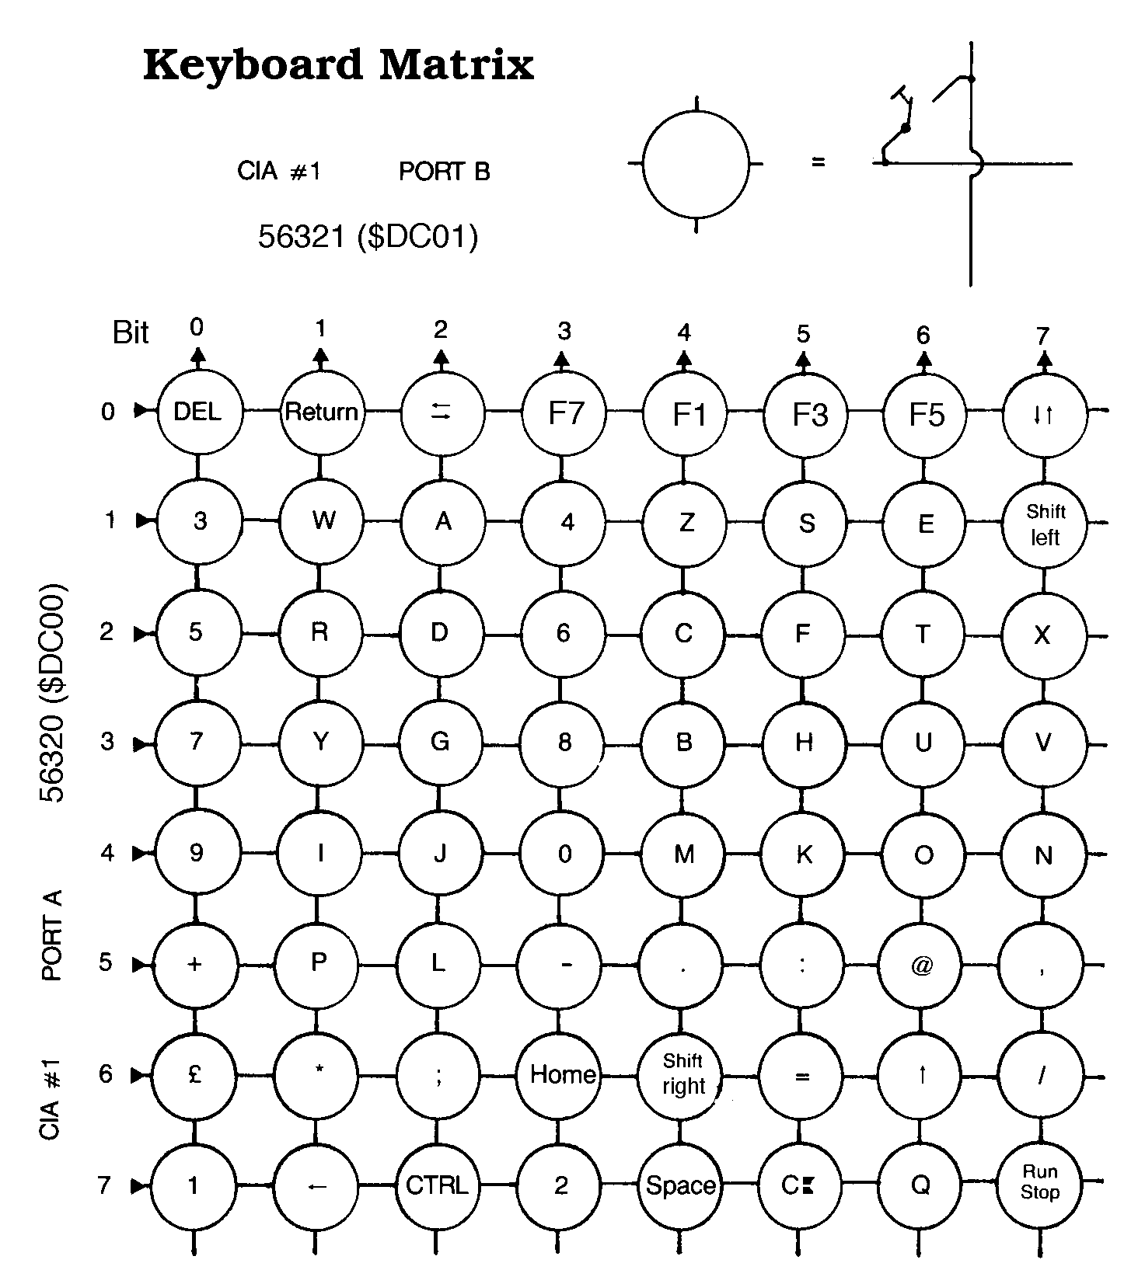
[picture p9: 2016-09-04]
emudoc/emucc/schematics/keymatrix.gif

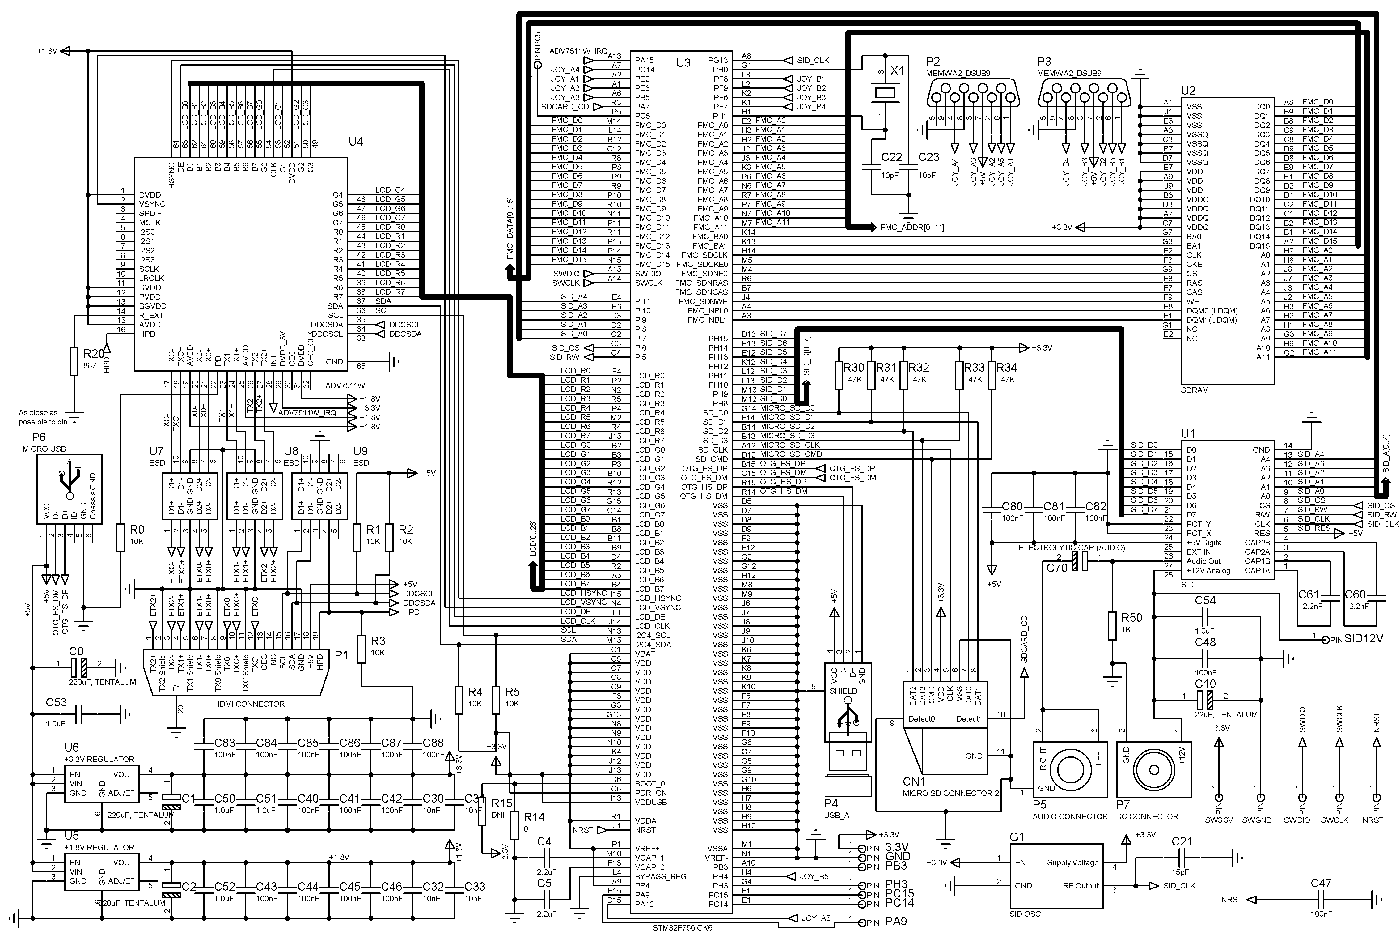
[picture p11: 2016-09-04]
pcb/mk2/schematics.png

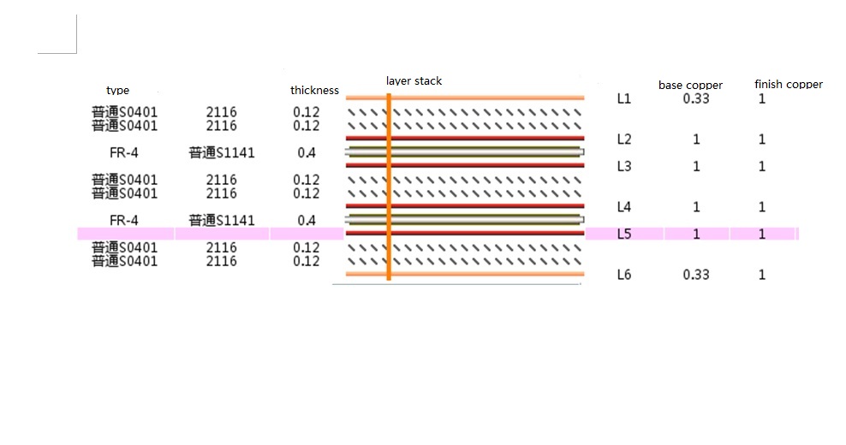
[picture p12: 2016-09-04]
pcb/mk2/layer_stack.jpg

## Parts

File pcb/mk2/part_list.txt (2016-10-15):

U3, 1 MCU, STM32F756IGK6 (to be changed)
U4, 1 HDMI transmitter, ADV7511WBSWZ
U2, 1 SDRAM, IS42S16400J-5BL
CN1, 1 SDCARD, 104031-0811
P2-P3, 2 D-SUB9, XM3C-0942-112LS
P5, 1 Audio connector, SJ-3523-SMT-TR
P7, 1 DC power connector, PJ-037A
P1, 1 HDMI connector, 10029449-001RLF
P4, 1 USB-A connector, 62900416021
P6, 1 USB micro connector, 47590-0001
U1, 1 IC-sockel, DIL 28 SMD, 114-87-628-41-117101
C10, 1 Tantalum Capacitor, TAJB226M016RNJ
C0-C2, 3 Tantalum Capacitors, TMCMB0J227MTRF
C70, 1 AUDIO capacitor, RFS-50V010ME3#5
U6, 1 Volt regulator (3.3V), NCP5662DS33R4G
U5, 1 Volt regulator (1.8V), NCP5662DS18R4G
G1, 1 1Mhz Oscillator (SID), FXO-HC735-1MHZ
X1, 1 8Mhz Crystal, FQ7050B-8
U7-U9, 3 TPD4S010DQAR
C4-C5, 2 2.2uF (0603)
C21, 1 15pF (0603)
C22-C23, 2 10pF (0603)
C30-C33, 4 10nF (0603)
C40-C46, C47-C48, C80-C88, 14 100nF (0603)
C50-C54, 5 1.0uF (0603)
C60-C61, 2 2.2nF (0603)
R0-R5, 6 10K (0603)
R14, 1 0 (0603)
R15, 1 DNI (0603)
R20, 1 887 (0603)
R30-R34, 5 47K (0603)
R50, 1 1K (0603)

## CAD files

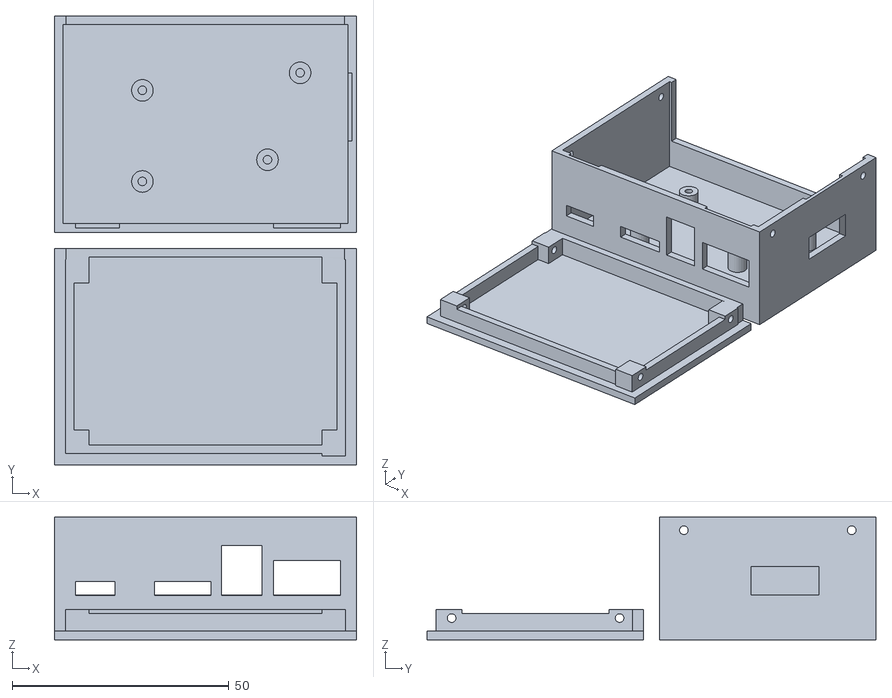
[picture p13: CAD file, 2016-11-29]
pcb/case/memwa2.stl
69.6 x 103.4 x 28.2

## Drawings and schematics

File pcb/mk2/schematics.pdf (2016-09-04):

U2

P2

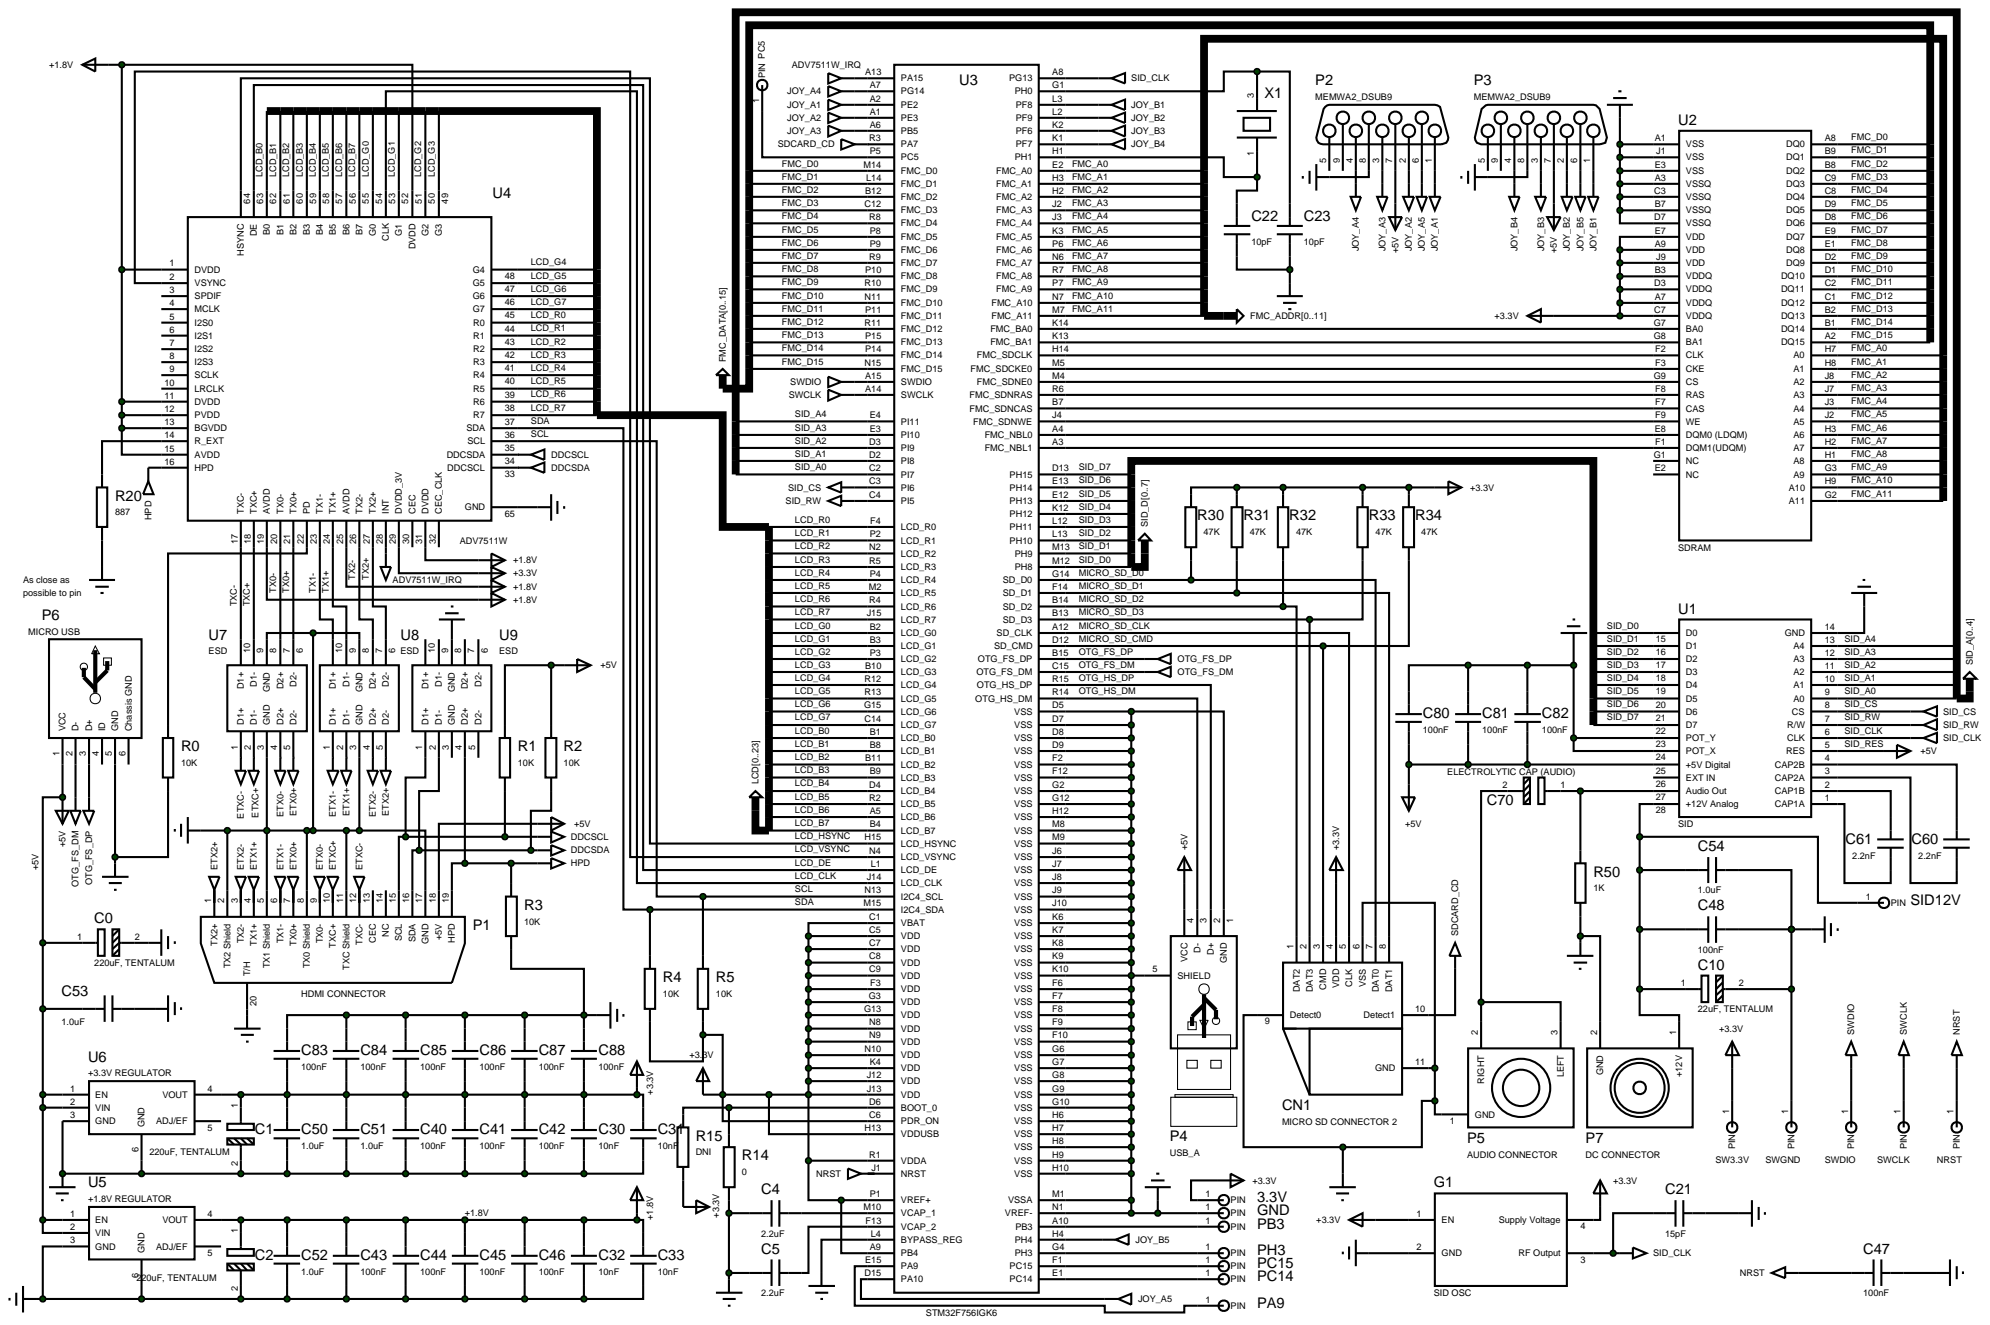
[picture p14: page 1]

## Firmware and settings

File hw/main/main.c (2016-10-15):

/*
 * memwa2 main
 *
 * Copyright (c) 2016 Mathias Edman <mail@dicetec.com>
 *
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
 */


/**
 * Main entry point. Handles main configuration of memory and setup.
 * It Aaso handles error codes and fw revision.
 */

#include "main.h"
#include "rng.h"
#include "config.h"
#include "diag.h"
#include "usbh_core.h"
#include "usbh_hid_keybd.h"
#include "console.h"
#include "keybd.h"
#include "if.h"
#include "romcc.h"
#include "romdd.h"
#include "stage.h"
#include "disp.h"
#include "ff.h"
#include "sm.h"
#include "sdcard.h"

#define BUFFER_SIZE        0x1000
#define DEFAULT_KEY_MAX    71

extern if_emu_cc_t g_if_cc_emu;
extern if_emu_dd_t g_if_dd_emu;

static char *g_rom_path_pp[4] =
{
  "0:/rom/cc_brom.bin",
  "0:/rom/cc_crom.bin",
  "0:/rom/cc_krom.bin",
  "0:/rom/dd_dos.bin"
};

static char *g_conf_path_pp[2] =
{
  "0:/conf/palette.cfg",
  "0:/conf/key.cfg"
};

static uint32_t g_clut_a[16];
static if_keybd_map_t g_keybd_map_a[DEFAULT_KEY_MAX + 1];

static FATFS g_fatfs;
static char g_sd_path_p[] = {"0:/"};

int main()
{
    FIL fd;
    FRESULT res;
    diag_status_t diag_status = DIAG_STATUS_OK;
    uint32_t bytes_read = 0;
    uint32_t read_cnt = 0;
    uint32_t i;

    __set_PRIMASK(0); /* Enable IRQ */

    HAL_Init();

    HAL_Delay(200);

    config_init();

    /* Clean sdram */
    for(i = 0; i < SDRAM_SIZE; i++)
    {
        *(uint8_t *)(SDRAM_ADDR + i) = 0;
    }

    /* Card inserted ? */
    if(sdcard_inserted() == 0)
    {
        /* If not insterted, then run full diagnostic */
        diag_status = diag_run();

        if(diag_status != DIAG_STATUS_OK)
        {
            main_error("Diagnostic did not pass!", __FILE__, __LINE__, (uint32_t)diag_status);
            while(1){;}
        }

        while(1)
        {
            /* If not, then just try again */
            if(sdcard_inserted() == 1)
            {
                sdcard_init();
                HAL_Delay(1000);
                diag_status = diag_sdcard_run();
                if(diag_status != DIAG_STATUS_OK)
                {
                    main_error("Diagnostic did not pass!", __FILE__, __LINE__, (uint32_t)diag_status);
                }
                break;
            }
        }
    }

    disp_set_memory(MEM_ADDR_BUFFER0, CC_DISP_BUFFER1_ADDR);
    disp_set_memory(MEM_ADDR_BUFFER1, CC_DISP_BUFFER2_ADDR);
    disp_set_memory(MEM_ADDR_BUFFER2, CC_DISP_BUFFER3_ADDR);

    if(f_mount(&g_fatfs, (TCHAR const*)g_sd_path_p, 1) != FR_OK)
    {
        main_error("Failed to mount filesystem!", __FILE__, __LINE__, 0);
    }

    /* Try and load basic rom from sd card */
    res = f_open(&fd, g_rom_path_pp[0], FA_READ);

    if(res == FR_OK)
    {
        read_cnt = 0;
        while(read_cnt != IF_MEMORY_CC_BROM_ACTUAL_SIZE)
        {
            f_read(&fd, (uint8_t *)(CC_BROM_BASE_ADDR + CC_BROM_LOAD_ADDR + read_cnt), BUFFER_SIZE, (UINT *)&bytes_read);
            if(res != FR_OK || bytes_read == 0)
            {
                main_warning("Error reading rom file (brom)!", __FILE__, __LINE__, read_cnt);
                break;
            }
            read_cnt += bytes_read;
        }
        f_close(&fd);
    }
    else
    {
        /* No file found, load the default one */
        memcpy((uint8_t *)(CC_BROM_BASE_ADDR + CC_BROM_LOAD_ADDR), rom_cc_get_memory(ROM_CC_SECTION_BROM), IF_MEMORY_CC_BROM_ACTUAL_SIZE);
    }
 
     /* Try and load character rom from sd card */
    res = f_open(&fd, g_rom_path_pp[1], FA_READ);

    if(res == FR_OK)
    {
        read_cnt = 0;
        while(read_cnt != IF_MEMORY_CC_CROM_ACTUAL_SIZE)
        {
            f_read(&fd, (uint8_t *)(CC_CROM_BASE_ADDR + CC_CROM_LOAD_ADDR + read_cnt), BUFFER_SIZE, (UINT *)&bytes_read);
            if(res != FR_OK || bytes_read == 0)
            {
                main_warning("Error reading rom file (crom)!", __FILE__, __LINE__, read_cnt);
                break;
            }
            read_cnt += bytes_read;
        }
        f_close(&fd);
    }
    else
    {
        /* No file found, load the default one */
        memcpy((uint8_t *)(CC_CROM_BASE_ADDR + CC_CROM_LOAD_ADDR), rom_cc_get_memory(ROM_CC_SECTION_CROM), IF_MEMORY_CC_CROM_ACTUAL_SIZE);
    }

     /* Try and load kernal rom from sd card */
    res = f_open(&fd, g_rom_path_pp[2], FA_READ);

    if(res == FR_OK)
    {
        read_cnt = 0;
        while(read_cnt != IF_MEMORY_CC_KROM_ACTUAL_SIZE)
        {
            f_read(&fd, (uint8_t *)(CC_KROM_BASE_ADDR + CC_KROM_LOAD_ADDR + read_cnt), BUFFER_SIZE, (UINT *)&bytes_read);
            if(res != FR_OK || bytes_read == 0)
            {
                main_warning("Error reading rom file (krom)!", __FILE__, __LINE__, read_cnt);
                break;
            }
            read_cnt += bytes_read;
        }
        f_close(&fd);
    }
    else
    {
        /* No file found, load the default one */
        memcpy((uint8_t *)(CC_KROM_BASE_ADDR + CC_KROM_LOAD_ADDR), rom_cc_get_memory(ROM_CC_SECTION_KROM), IF_MEMORY_CC_KROM_ACTUAL_SIZE);
    }

     /* Try and load dos rom from sd card */
    res = f_open(&fd, g_rom_path_pp[3], FA_READ);

    if(res == FR_OK)
    {
        read_cnt = 0;
        while(read_cnt != IF_MEMORY_DD_DOS_ACTUAL_SIZE)
        {
            res = f_read(&fd, (uint8_t *)(DD_ALL_BASE_ADDR + DD_DOS_LOAD_ADDR + read_cnt), BUFFER_SIZE, (UINT *)&bytes_read);
            if(res != FR_OK || bytes_read == 0)
            {
                main_warning("Error reading rom file (dos)!", __FILE__, __LINE__, read_cnt);
                break;
            }
            read_cnt += bytes_read;
        }
        f_close(&fd);
    }
    else
    {
        /* No file found, load the default one */
        memcpy((uint8_t *)(DD_ALL_BASE_ADDR + DD_DOS_LOAD_ADDR), rom_dd_get_memory(ROM_DD_SECTION_DOS), IF_MEMORY_DD_DOS_ACTUAL_SIZE);
    }

     /* Try and load palette conf from sd card */
    res = f_open(&fd, g_conf_path_pp[0], FA_READ);

    if(res == FR_OK)
    {
        uint8_t palette_string_p[256];
        char *colors_pp[28];
        uint8_t colors_cnt = 0;
        char delimiter_p[2] = "\n";
        uint32_t color;

        memset(colors_pp, 0x00, 16 * sizeof(char *));

        f_read(&fd, (uint8_t *)palette_string_p, BUFFER_SIZE, (UINT *)&bytes_read);

        if(res != FR_OK || bytes_read == 0)
        {
            main_warning("Error reading file (palette)!", __FILE__, __LINE__, 0);
        }

        colors_pp[colors_cnt] = strtok((char *)palette_string_p, delimiter_p);
        colors_cnt++;
        while(colors_pp[colors_cnt-1] != NULL)
        {
            /* Get the color asciihex string */
            colors_pp[colors_cnt] = strtok(NULL, delimiter_p);

            /* Get the 32 bit value */
            color = strtoul(colors_pp[colors_cnt], NULL, 16);

            /* Add to collection */
            g_clut_a[colors_cnt] = color;

            colors_cnt++;
        }

        f_close(&fd);

        disp_set_clut_table(g_clut_a);
    }
    else
    {
        ; /* No file found, the default clut table will be used in disp.c */
    }

     /* Try and load key conf from sd card */
    res = f_open(&fd, g_conf_path_pp[1], FA_READ);

    if(res == FR_OK)
    {
        uint8_t key_string_p[1024]; /* 16 chars max on one row */

        f_read(&fd, (uint8_t *)key_string_p, 1024, (UINT *)&bytes_read);

        if(res != FR_OK || bytes_read == 0)
        {
            main_warning("Error reading file (palette)!", __FILE__, __LINE__, 0);
        }

        keybd_populate_map(key_string_p, g_keybd_map_a);

        f_close(&fd);
    }
    else
    {
        /* No file found, load the default configuration */
        memcpy((uint8_t *)g_keybd_map_a,
               keybd_get_default_map(),
               DEFAULT_KEY_MAX * sizeof(if_keybd_map_t));
    }

    stage_init(CC_STAGE_FILES_ADDR);
    stage_select_layer(0);

    /* Give commodore computer (cc) some memory to work with */
    g_if_cc_emu.if_emu_cc_mem.mem_set_fp((uint8_t *)CC_RAM_BASE_ADDR, IF_MEM_CC_TYPE_RAM);
    g_if_cc_emu.if_emu_cc_mem.mem_set_fp((uint8_t *)CC_BROM_BASE_ADDR, IF_MEM_CC_TYPE_BROM);
    g_if_cc_emu.if_emu_cc_mem.mem_set_fp((uint8_t *)CC_CROM_BASE_ADDR, IF_MEM_CC_TYPE_CROM);
    g_if_cc_emu.if_emu_cc_mem.mem_set_fp((uint8_t *)CC_KROM_BASE_ADDR, IF_MEM_CC_TYPE_KROM);
    g_if_cc_emu.if_emu_cc_mem.mem_set_fp((uint8_t *)CC_IO_BASE_ADDR, IF_MEM_CC_TYPE_IO);
    g_if_cc_emu.if_emu_cc_mem.mem_set_fp((uint8_t *)CC_UTIL1_BASE_ADDR, IF_MEM_CC_TYPE_UTIL1); /* subscription read storage by emu */
    g_if_cc_emu.if_emu_cc_mem.mem_set_fp((uint8_t *)CC_UTIL2_BASE_ADDR, IF_MEM_CC_TYPE_UTIL2); /* subscription write storage by emu */
    g_if_cc_emu.if_emu_cc_mem.mem_set_fp((uint8_t *)CC_SPRITE1_BASE_ADDR, IF_MEM_CC_TYPE_SPRITE1); /* sprite virtual layer (background) by emu */
    g_if_cc_emu.if_emu_cc_mem.mem_set_fp((uint8_t *)CC_SPRITE2_BASE_ADDR, IF_MEM_CC_TYPE_SPRITE2); /* sprite virtual layer (forground) by emu */
    g_if_cc_emu.if_emu_cc_mem.mem_set_fp((uint8_t *)CC_SPRITE3_BASE_ADDR, IF_MEM_CC_TYPE_SPRITE3); /* sprite mapping by emu */

    /* Give disk drive (dd) some memory to work with */
    g_if_dd_emu.if_emu_dd_mem.mem_set_fp((uint8_t *)DD_ALL_BASE_ADDR, IF_MEM_DD_TYPE_ALL);
    g_if_dd_emu.if_emu_dd_mem.mem_set_fp((uint8_t *)DD_UTIL1_BASE_ADDR, IF_MEM_DD_TYPE_UTIL1);
    g_if_dd_emu.if_emu_dd_mem.mem_set_fp((uint8_t *)DD_UTIL2_BASE_ADDR, IF_MEM_DD_TYPE_UTIL2);

    g_if_cc_emu.if_emu_cc_display.display_layer_set_fp((uint8_t *)CC_DISP_BUFFER2_ADDR);
    g_if_cc_emu.if_emu_cc_ue.ue_keybd_map_set_fp(g_keybd_map_a);

    sm_init();
    sm_run();
}


void main_error(char *string_p, char *file_p, uint32_t line, uint32_t extra)
{
    printf("[ERR] %s (%lu)\n", string_p, extra);
    stage_set_message(string_p);
    if(sm_get_state() == SM_STATE_EMULATOR && sm_get_disp_stats_flag())
    {
        stage_draw_info(INFO_PRINT, 0   );
    }
    //printf("[%s:%lu] %s\n", file_p, line, string_p);
}

void main_warning(char *string_p, char *file_p, uint32_t line, uint32_t extra)
{
    printf("[ERR] %s (%lu)\n", string_p, extra);
    //printf("[%s:%lu] %s\n", file_p, line, string_p);
}

char *main_get_fw_revision()
{
    return FW_REVISION;
}

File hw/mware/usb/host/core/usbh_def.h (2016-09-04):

/**
  ******************************************************************************
  * @file    usbh_def.h
  * @author  MCD Application Team
  * @version V3.2.2
  * @date    07-July-2015
  * @brief   Definitions used in the USB host library
  ******************************************************************************
  * @attention
  *
  * <h2><center>&copy; COPYRIGHT 2015 STMicroelectronics</center></h2>
  *
  * Licensed under MCD-ST Liberty SW License Agreement V2, (the "License");
  * You may not use this file except in compliance with the License.
  * You may obtain a copy of the License at:
  *
  *        http://www.st.com/software_license_agreement_liberty_v2
  *
  * Unless required by applicable law or agreed to in writing, software 
  * distributed under the License is distributed on an "AS IS" BASIS, 
  * WITHOUT WARRANTIES OR CONDITIONS OF ANY KIND, either express or implied.
  * See the License for the specific language governing permissions and
  * limitations under the License.
  *
  ******************************************************************************
  */
 
/* Define to prevent recursive  ----------------------------------------------*/
#ifndef  USBH_DEF_H
#define  USBH_DEF_H

#ifdef __cplusplus
 extern "C" {
#endif

/* Includes ------------------------------------------------------------------*/
#include "usbh_conf.h"

/** @addtogroup USBH_LIB
  * @{
  */

/** @addtogroup USBH_LIB_CORE
* @{
*/
  
/** @defgroup USBH_DEF
  * @brief This file is includes USB descriptors
  * @{
  */ 

#ifndef NULL
#define NULL  0
#endif

#ifndef FALSE
#define FALSE 0
#endif

#ifndef TRUE
#define TRUE  1
#endif


#define ValBit(VAR,POS)                               (VAR & (1 << POS))
#define SetBit(VAR,POS)                               (VAR |= (1 << POS))
#define ClrBit(VAR,POS)                               (VAR &= ((1 << POS)^255))

#define  LE16(addr)             (((uint16_t)(*((uint8_t *)(addr))))\
                                + (((uint16_t)(*(((uint8_t *)(addr)) + 1))) << 8))

#define  LE16S(addr)              (uint16_t)(LE16((addr)))

#define  LE32(addr)              ((((uint32_t)(*(((uint8_t *)(addr)) + 0))) + \
                                              (((uint32_t)(*(((uint8_t *)(addr)) + 1))) << 8) + \
                                              (((uint32_t)(*(((uint8_t *)(addr)) + 2))) << 16) + \
                                              (((uint32_t)(*(((uint8_t *)(addr)) + 3))) << 24)))

#define  LE64(addr)              ((((uint64_t)(*(((uint8_t *)(addr)) + 0))) + \
                                              (((uint64_t)(*(((uint8_t *)(addr)) + 1))) <<  8) +\
                                              (((uint64_t)(*(((uint8_t *)(addr)) + 2))) << 16) +\
                                              (((uint64_t)(*(((uint8_t *)(addr)) + 3))) << 24) +\
                                              (((uint64_t)(*(((uint8_t *)(addr)) + 4))) << 32) +\
                                              (((uint64_t)(*(((uint8_t *)(addr)) + 5))) << 40) +\
                                              (((uint64_t)(*(((uint8_t *)(addr)) + 6))) << 48) +\
                                              (((uint64_t)(*(((uint8_t *)(addr)) + 7))) << 56)))


#define  LE24(addr)              ((((uint32_t)(*(((uint8_t *)(addr)) + 0))) + \
                                              (((uint32_t)(*(((uint8_t *)(addr)) + 1))) << 8) + \
                                              (((uint32_t)(*(((uint8_t *)(addr)) + 2))) << 16)))


#define  LE32S(addr)              (int32_t)(LE32((addr)))



#define  USB_LEN_DESC_HDR                               0x02
#define  USB_LEN_DEV_DESC                               0x12
#define  USB_LEN_CFG_DESC                               0x09
#define  USB_LEN_IF_DESC                                0x09
#define  USB_LEN_EP_DESC                                0x07
#define  USB_LEN_OTG_DESC                               0x03
#define  USB_LEN_SETUP_PKT                              0x08

/* bmRequestType :D7 Data Phase Transfer Direction  */
#define  USB_REQ_DIR_MASK                               0x80
#define  USB_H2D                                        0x00
#define  USB_D2H                                        0x80

/* bmRequestType D6..5 Type */
#define  USB_REQ_TYPE_STANDARD                          0x00
#define  USB_REQ_TYPE_CLASS                             0x20
#define  USB_REQ_TYPE_VENDOR                            0x40
#define  USB_REQ_TYPE_RESERVED                          0x60

/* bmRequestType D4..0 Recipient */
#define  USB_REQ_RECIPIENT_DEVICE                       0x00
#define  USB_REQ_RECIPIENT_INTERFACE                    0x01
#define  USB_REQ_RECIPIENT_ENDPOINT                     0x02
#define  USB_REQ_RECIPIENT_OTHER                        0x03
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

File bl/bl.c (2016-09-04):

/*
 * memwa2 bootloader
 *
 * Copyright (c) 2016 Mathias Edman <mail@dicetec.com>
 *
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
 */


#include "bl.h"
#include "disp.h"
#include "sdcard.h"
#include "ff.h"
#include "stm32f7xx_hal_flash.h"
#include "stm32f7xx_hal_rcc.h"

#define BUFFER_SIZE        512

#define ADDR_FLASH_SECTOR_0     ((uint32_t)0x08000000) /* Base address of Sector 0, 32 Kbytes */
#define ADDR_FLASH_SECTOR_1     ((uint32_t)0x08008000) /* Base address of Sector 1, 32 Kbytes */
#define ADDR_FLASH_SECTOR_2     ((uint32_t)0x08010000) /* Base address of Sector 2, 32 Kbytes */
#define ADDR_FLASH_SECTOR_3     ((uint32_t)0x08018000) /* Base address of Sector 3, 32 Kbytes */
#define ADDR_FLASH_SECTOR_4     ((uint32_t)0x08020000) /* Base address of Sector 4, 128 Kbytes */
#define ADDR_FLASH_SECTOR_5     ((uint32_t)0x08040000) /* Base address of Sector 5, 256 Kbytes */
#define ADDR_FLASH_SECTOR_6     ((uint32_t)0x08070000) /* Base address of Sector 6, 256 Kbytes */
#define ADDR_FLASH_SECTOR_7     ((uint32_t)0x080A0000) /* Base address of Sector 7, 256 Kbytes */

#define FLASH_USER_START_ADDR   ADDR_FLASH_SECTOR_4
#define FW_PATH_AND_NAME        "0:/target.bin"
#define FW_PATH                 "0:/"

typedef void (*jump_function_t)();

static uint32_t get_sector(uint32_t addr)
{
  uint32_t sector = 0;

  if((addr < ADDR_FLASH_SECTOR_1) && (addr >= ADDR_FLASH_SECTOR_0))
  {
    sector = FLASH_SECTOR_0;
  }
  else if((addr < ADDR_FLASH_SECTOR_2) && (addr >= ADDR_FLASH_SECTOR_1))
  {
    sector = FLASH_SECTOR_1;
  }
  else if((addr < ADDR_FLASH_SECTOR_3) && (addr >= ADDR_FLASH_SECTOR_2))
  {
    sector = FLASH_SECTOR_2;
  }
  else if((addr < ADDR_FLASH_SECTOR_4) && (addr >= ADDR_FLASH_SECTOR_3))
  {
    sector = FLASH_SECTOR_3;
  }
  else if((addr < ADDR_FLASH_SECTOR_5) && (addr >= ADDR_FLASH_SECTOR_4))
  {
    sector = FLASH_SECTOR_4;
  }
  else if((addr < ADDR_FLASH_SECTOR_6) && (addr >= ADDR_FLASH_SECTOR_5))
  {
    sector = FLASH_SECTOR_5;
  }
  else if((addr < ADDR_FLASH_SECTOR_7) && (addr >= ADDR_FLASH_SECTOR_6))
  {
    sector = FLASH_SECTOR_6;
  }
  else /* (addr < FLASH_END_ADDR) && (addr >= ADDR_FLASH_SECTOR_7) */
  {
    sector = FLASH_SECTOR_7;
  }
  return sector;
}

static void erase_flash()
{
    FLASH_EraseInitTypeDef EraseInitStruct;
    uint32_t first_sector = 0;
    uint32_t nbr_sectors = 0;
    uint32_t error_sector = 0;
    HAL_StatusTypeDef res_flash;

    first_sector = get_sector(ADDR_FLASH_SECTOR_4);
    nbr_sectors = get_sector(ADDR_FLASH_SECTOR_7) - first_sector + 1;

    EraseInitStruct.TypeErase     = FLASH_TYPEERASE_SECTORS;
    EraseInitStruct.VoltageRange  = FLASH_VOLTAGE_RANGE_3;
    EraseInitStruct.Sector        = first_sector;
    EraseInitStruct.NbSectors     = nbr_sectors;

    /* Note: If an erase operation in Flash memory also concerns data in the data or instruction cache,
     you have to make sure that these data are rewritten before they are accessed during code
     execution. If this cannot be done safely, it is recommended to flush the caches by setting the
     DCRST and ICRST bits in the FLASH_CR register. */
    res_flash = HAL_FLASHEx_Erase(&EraseInitStruct, &error_sector);
    if(res_flash != HAL_OK)
    {
        while(1) {;}
    }
}

static void jump_to_application()
{
    uint32_t jump_addr = *(uint32_t *)(ADDR_FLASH_SECTOR_4 + 4);
    jump_function_t jump_function = (jump_function_t)jump_addr;

    HAL_RCC_DeInit();
    SysTick->CTRL = 0;
    SysTick->LOAD = 0;
    SysTick->VAL = 0;

    __set_MSP(*(uint32_t*)ADDR_FLASH_SECTOR_4);

    jump_function();

}

static void config_clks()
{
    RCC_OscInitTypeDef RCC_OscInitStruct;
    RCC_ClkInitTypeDef RCC_ClkInitStruct;
    RCC_PeriphCLKInitTypeDef PeriphClkInitStruct;

    __HAL_RCC_PWR_CLK_ENABLE();

    __HAL_PWR_VOLTAGESCALING_CONFIG(PWR_REGULATOR_VOLTAGE_SCALE1);

#ifdef USE_HSE
    RCC_OscInitStruct.OscillatorType = RCC_OSCILLATORTYPE_HSE;
    RCC_OscInitStruct.HSEState = RCC_HSE_ON;
    RCC_OscInitStruct.PLL.PLLSource = RCC_PLLSOURCE_HSE;
    RCC_OscInitStruct.PLL.PLLM = 8;
#else
    RCC_OscInitStruct.OscillatorType = RCC_OSCILLATORTYPE_HSI;
    RCC_OscInitStruct.HSIState = RCC_HSI_ON;
    RCC_OscInitStruct.HSICalibrationValue = 16;
    RCC_OscInitStruct.PLL.PLLSource = RCC_PLLSOURCE_HSI;
    RCC_OscInitStruct.PLL.PLLM = 16;
#endif  
    RCC_OscInitStruct.PLL.PLLState = RCC_PLL_ON;
    RCC_OscInitStruct.PLL.PLLN = 432;
    RCC_OscInitStruct.PLL.PLLP = RCC_PLLP_DIV2;
    RCC_OscInitStruct.PLL.PLLQ = 9;

    HAL_RCC_OscConfig(&RCC_OscInitStruct);

    HAL_PWREx_EnableOverDrive();

    RCC_ClkInitStruct.ClockType = RCC_CLOCKTYPE_HCLK |
                                  RCC_CLOCKTYPE_SYSCLK |
                                  RCC_CLOCKTYPE_PCLK1 |
                                  RCC_CLOCKTYPE_PCLK2;
    RCC_ClkInitStruct.SYSCLKSource = RCC_SYSCLKSOURCE_PLLCLK;
    RCC_ClkInitStruct.AHBCLKDivider = RCC_SYSCLK_DIV1;
    RCC_ClkInitStruct.APB1CLKDivider = RCC_HCLK_DIV4;
    RCC_ClkInitStruct.APB2CLKDivider = RCC_HCLK_DIV4;
    HAL_RCC_ClockConfig(&RCC_ClkInitStruct, FLASH_LATENCY_4);

    PeriphClkInitStruct.PeriphClockSelection = RCC_PERIPHCLK_LTDC |
                                               RCC_PERIPHCLK_I2C4 |
                                               RCC_PERIPHCLK_SDMMC1 |
                                               RCC_PERIPHCLK_CLK48;
    PeriphClkInitStruct.PLLSAI.PLLSAIN = 320;
    PeriphClkInitStruct.PLLSAI.PLLSAIR = 4;
    PeriphClkInitStruct.PLLSAI.PLLSAIQ = 2;
    PeriphClkInitStruct.PLLSAI.PLLSAIP = RCC_PLLSAIP_DIV8;
    PeriphClkInitStruct.PLLSAIDivQ = 1;
    PeriphClkInitStruct.PLLSAIDivR = RCC_PLLSAIDIVR_2;
    PeriphClkInitStruct.I2c4ClockSelection = RCC_I2C4CLKSOURCE_HSI;
    PeriphClkInitStruct.Clk48ClockSelection = RCC_CLK48SOURCE_PLL;
    PeriphClkInitStruct.Sdmmc1ClockSelection = RCC_SDMMC1CLKSOURCE_CLK48;
    HAL_RCCEx_PeriphCLKConfig(&PeriphClkInitStruct);

    /* SysTick_IRQn interrupt configuration */
    HAL_NVIC_SetPriority(SysTick_IRQn, 1, 1);
}
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

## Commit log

2016-10-15 First patch to support stm32f767xx
2016-10-15 Fixed bug with ltdc config
    Pin PG12 was configured with wrong alternative function.
    [config.c, main.h]
2016-10-15 Activated clock for GPIO port B
    * Fixed bug with joystick port A (right)
    * Corrected typo for i2c structures
    * Added D-Sub part to part list
    [adv7511.c, config.c, main.h]
2016-10-15 Fixed bug with sound
    The timing constraint "Tvd" is now fulfilled.
    [config.c, main.h, sidbus.c]
2016-10-16 Updated hal lib to V1.5.0
    This commit also replaced files related to the
    switch from the old stm32f756xx MCU to the newer
    stm32f767xx. Some unused files were also removed.
    [config.c, main.h]
2016-10-16 Changed polarity of pixel clock
    Pixel clock now have correct polarity. Pretty
    amazing that it was working before with stm32f756.
    [disp.c, main.h]
2016-10-16 Implemented a write lock for sidbus
    Sometimes a write to sidbus will be called before
    previous write has been completed. This will lead
    to wrong and/or missed write cycles. A busy wait
    loop has been implemented as a fix for this.
    Also some indentation was fixed in this patch.Z
    [main.h, sdram.c, sidbus.c]
2016-11-29 Added model for case
    [memwa2.stl]

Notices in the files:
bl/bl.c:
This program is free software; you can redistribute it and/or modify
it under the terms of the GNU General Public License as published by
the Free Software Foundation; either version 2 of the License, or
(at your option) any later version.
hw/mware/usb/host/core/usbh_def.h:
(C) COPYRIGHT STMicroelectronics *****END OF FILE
